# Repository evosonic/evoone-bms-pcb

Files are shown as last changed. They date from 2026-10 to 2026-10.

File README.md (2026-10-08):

# EvoOne BMS PCB (EVO2513 v0.5.0)

KiCad project for the EvoOne battery management board, EVO2513 revision 0.5.0.

The design was converted to KiCad from the Altium sources supplied by Lattech.
The raw import needed several fixes before the schematic and PCB agreed; see
[Fixes after import](#fixes-after-import).

## Board

| | |
|---|---|
| Outline | 110 × 69 mm |
| Layers | 8 copper (F.Cu, In1–In6.Cu, B.Cu) |
| Thickness | 1.584 mm |
| Components | ~230 footprints |
| Tool | KiCad 10.0 |

## Schematic sheets

The schematic is hierarchical: the root sheet `EVO2513-0_5_0.kicad_sch` holds
one sheet symbol per sheet, and each sheet is its own file. Open it from
`EVO2513-0_5_0.kicad_pro`.

| Sheet | Function | Key parts |
|---|---|---|
| S01 External Connectors | Board connectors, mounting and pogo test pads | J1–J6, BON1–26 |
| S02 Input Protection | Over/under-voltage and reverse-voltage protection on the input | LTC4365, DMT4011LFG N-FETs |
| S03 BMS Input and Output Monitor | Input/output current sensing and power-path switching | LTC1960, DMP3018SFV P-FETs, 2512 shunts |
| S04 Charger Regulation | Charger switching stage | LTC1960, L1 4.7 µH |
| S05 Battery Management | Dual-battery selection and management | LTC1960 |
| S06 STEP-Up Step-Down Reg | Buck-boost output regulator | LM51772, L2 0.68 µH |
| S07 Load Switch and I-Sense | Output load switches and current-sense amplifiers | TPS22811 ×3, TLV9002 ×2 |
| S08 IO Expander | SPI I/O expander driving the rail enables and reading the faults | PCAL9714 |

The LTC1960 dual battery charger/selector is a single IC (U1) split across
sheets S03–S05.

Nets that cross sheets leave each sheet through a hierarchical label and a
pin on its sheet symbol, and the root sheet joins the pins with local
labels. There are no global labels; those nets are named from the root
(`/DCBMS`, `/POS1`, …). Labels between device sheets show the direction of
power or signal flow (e.g. DCFILTERED is an output of S02 and an input to
S03); links to the connector sheet, S01, stay passive. Labels used on only one sheet are local, and power
nets use power symbols.

## Connectors

| Ref | Part |
|---|---|
| J1 | Molex 1053101204, 2.5 mm pitch |
| J2 | Molex 1053101114, 14-way 2.5 mm pitch, vertical |
| J3 | Amphenol BergStak 10144517-043802LF, 40-pin 0.8 mm receptacle |
| J4 | Molex 1053102204, 2.5 mm pitch |
| J5, J6 | Molex 1053091102, 2-way 2.5 mm pitch |

## Files

- `EVO2513-0_5_0.kicad_pro` — project
- `EVO2513-0_5_0.kicad_sch` — root schematic sheet; `S0x *.kicad_sch` — the
  eight sheets
- `EVO2513-0_5_0.kicad_pcb` — PCB layout
- `EVO2513-0_5_0-import-fps.pretty/` — project footprint library (footprints
  extracted by the Altium import), registered in `fp-lib-table`. Chip resistors
  and capacitors instead use KiCad's standard `Resistor_SMD` and
  `Capacitor_SMD` libraries
- `EVO2513-0_5_0-lattech.kicad_sym` — project symbol library (nickname
  `Lattech Systems`): the Lattech symbols used by the board, extracted from
  the schematics, plus symbols added for the W16 changes (resistor values, PCAL9714). It is not the complete Lattech library, which was not supplied.
- `EVO2513-0_5_0-altium-import.kicad_sym` — the 4 power symbols created by the
  Altium import. Both symbol libraries are registered in `sym-lib-table`.
- `744393580068.stp` — STEP model for part 744393580068 (not currently
  referenced by any footprint in the PCB)

## Design changes (W16 review)

Part and value changes from the W16 schematic review. None changes a
connection or the board copper.

| Ref | Was | Now | Why |
|---|---|---|---|
| Q1, Q3 | DMT4011LFG 40 V | DMT6007LFGQ-7 60 V | Margin against D1's clamp voltage |
| D1 | 1.5SMB27CA | SMBJ26CA (Littelfuse) | Stand-off above the 24 V supply; 42.1 V clamp |
| L1 | 4.7 µH SRP1265A-4R7M | 10 µH SRP1265A-100M | LTC1960's 10 µH minimum |
| C10 | 100 nF 16 V | 100 nF 50 V CC0402KPX7R9BB104 | Sits on VPLUS at ~23 V |
| R54 | 1 kΩ | 768 Ω RC0402FR-07768RL | SBC load-switch current limit (R22, R53, R71 stay 1 kΩ) |
| C16 | 220 nF 50 V C0G 0805 | 220 nF 50 V X7R CC0805KFX7R9BB224 | No 220 nF C0G 0805 exists |
| C39 | 470 pF | 1 nF | SW2 snubber, boost-mode ringing |
| C3, C11, C12, C55 | 35 V | 50 V | DCFILTERED / DCBMS / DCSENSED at 26.3 V |
| C44, C45, C48–C50, C54 | 16 V | 50 V | +12 V and the switched outputs |
| R1 | 620K (description 619K) | 619K | Value and description now agree |
| D4 | Pins named as a series pair | Pins named for the fitted common-anode BAT54A | Drawing and wiring were already right |

Connection options on U5 (LM51772), as 0R 0402 links so either build can be
fitted (lower right of S06):

| Pin | Fitted | DNP (alternative) |
|---|---|---|
| MODE (7) | R86 to GND: power-save mode (W16 review) | R87 back to VCC2/ILIMCOMP: forced PWM, as built before |
| BIAS (40) | R88 to DCBMS, as built before | R89 to +12V, still under review |

U5 can also be configured over I2C instead of by its CFG resistors (right of
the MODE/BIAS links on S06, all DNP as built):

| Ref | Part | Function in the I2C build |
|---|---|---|
| R103 | 0R, CFG1 (ADDR/SLOPE, pin 9) to GND | Enables I2C at address 0x6A. R38 can stay; R103 shorts it |
| R104 | 0R, SDA/CFG3 (pin 5) to J3.34 `MCU_ENDAQ` | SDA to the MCU |
| R105 | 0R, SCL/CFG4 (pin 6) to J3.36 `MCU_ENEXT` | SCL to the MCU |
| R106, R107 | 2.2K to +3V3MCU | SDA and SCL pull-ups (pins rated to 5.8 V) |
| R30, R29 | 5.1K and 1.87K to GND | **Remove**: they are CFG3/CFG4 and would load the bus |

To build for I2C, fit R103–R107 and remove R29 and R30. J3.34 and J3.36 are
also the direct-enable fallback through R97 and R98 (S08): fit R97/R98 or the
I2C option, never both. The MCU pins on J3.34/J3.36 must support I2C.

In the I2C build U5 starts from its register defaults, not the resistor
settings, so firmware must write them before raising REGEN. They are latched
for as long as DCBMS is up, since nRST is tied to DCBMS. Defaults that differ
from the resistor build:
- slope compensation is 0.875 (R38 selects 1.0)
- VCC1, DRSS, hiccup mode and the current-limit options come from registers
  instead of R30 and R29
- the internal DAC becomes the current-limit reference (`ILIM_THRESHOLD`);
  ILIMCOMP is tied to VCC2, so confirm the average current limit stays
  disabled

Overvoltage lockout on the load switches U6, U7 and U9 (TPS22811, S07): a 1 MΩ
1% resistor (R90, R91, R92) from +12V to nEN/OVLO (pin 2), with the
existing 100K 1% pull-downs R51, R52 and R70. Each switch turns off above
13.2 V (12.60–13.81 V over the ±2% pin threshold, 1% resistors and ±0.1 µA pin
leakage) and turns back on below 12.0 V (11.50–12.60 V). To revert, leave
R90–R92 unfitted.
Undervoltage lockout (11.4 V) is deferred: EN/UVLO (pin 1) is also the MCU
enable, and a tight threshold there needs a FET.

Rail enables and faults through a PCAL9714 SPI I/O expander (U11, new sheet
S08). It shares CLOCK/MOSI/MISO with U1 (LTC1960) and has its own chip
select, nCSIO, on J3.32, the pin that was ENSBC. Address 40h (ADDR to GND);
INT has a pull-up but isn't routed off the board. Both supplies are
+3V3MCU. RESET is held low by R100 (100K) and pulled to +3V3MCU by Q23
(BSS138, the same FET as Q20-Q22) whenever +12V is up: R99 100K /
R101 1M put about 11 V on its gate. With the 12 V rail off the expander is
in reset with every port an input, and RESET can never rise above
+3V3MCU, so nothing back-powers the expander. The switch point depends on
Q23's gate threshold (roughly 3.5-4 V on +12V with a BSS138) and has no hysteresis, so
firmware should wait for +12V before configuring the expander.

Q20–Q23 are onsemi BSS138 (SOT-23) in place of the DMN65D8LFB-7
(DFN1006, 1.0 × 0.6 mm). Use the plain BSS138 or another part without a
gate protection zener: the gates sit on 100K pull-ups (R63, R65, R78) and
the R99/R101 divider, and ESD-protected parts such as the 2N7002K or
BSS138BK leak up to about 10 µA, which would pull the PG high level down
by about 1 V. BSS138: IGSS 100 nA, IDSS 0.5 µA, VGS(th) 0.8–1.5 V.

| Port | Net | Function |
|---|---|---|
| P0_0–P0_2 (out) | ENDAQ, ENSBC, ENEXT | U6, U7, U9 enables |
| P0_4–P0_6 (in) | PGDAQ, PGSBC, PGEXT | U6, U7, U9 power good (also still drive the LEDs) |
| P0_7 (in) | nFLT | U5 nFLT/nINT, which was unconnected |
| P0_3, P1_0–P1_5 | — | spare, not connected |

REGEN (U5 enable, J3.12) stays separate: it is still driven straight from
J3 and doesn't pass through the expander.

J3 pins 34 and 36 are now `MCU_ENDAQ` and `MCU_ENEXT`. Each reaches its
enable only through a DNP 0R link (R97, R98), and J3.32
`nCSIO` has R95 (fitted) to the expander CS and R96 (DNP) to ENSBC. To go
back to driving an enable straight from J3, fit its link and leave that
expander port an input. The expander powers up with every port an input
and pulls off, so the existing pull-downs keep the rails off until
firmware sets P0_0–P0_2 as outputs. The MCU firmware must change for this:
the three load-switch enables move from GPIO to SPI, and nCSIO must idle high (R93
pulls it up).

These parts aren't on the board yet: run Update PCB from Schematic, then
place and route R86–R101, Q23, U11, C58 and C59, and re-place Q20–Q22
(now SOT-23). The ENDAQ, ENSBC and ENEXT
tracks from J3 need cutting at the new links.

Still to confirm against what was fitted: C2 (100 µF on the schematic,
82 µF `35SVPF82M` ordered) and C47 (4.7 nF on the schematic, 1.8 nF ordered).

## BOM consolidation

Parts with the same value in different packages or ratings now share one BOM
line. Each change keeps or raises the voltage rating and tolerance.
All resistors are 1%: the OVLO dividers moved from 1M/102K 0.1% to
1M/100K 1%, which keeps the lowest trip point at 12.60 V.

| Refs | Was | Now |
|---|---|---|
| C8, C9, C55 | 1 µF 50 V X5R 0402 | 1 µF 50 V X5R **0603**, as C23, C44, C45, C48–C50, C54 |
| C7, C52, C53, C58, C59 | 100 nF 16 V X7R 0402 | 100 nF **50 V** X7R 0402 `CC0402KPX7R9BB104`, as C10 |
| C37, C38 | 100 nF 16 V X7R 0603 | the same, **0402** (U5 bootstrap caps, ~5 V) |
| C17, C18, C20, C21, C34 | 100 nF 50 V X7R 0402, no part number | `CC0402KPX7R9BB104` |
| C11–C14, C24–C26 | 10 µF 25 V/50 V 1206 | 10 µF 50 V X7R **1210** Murata `GRM32ER71H106KA12L`, as C27 (1210 is easier to source) |
| C27 | 10 µF 50 V X5R 1210 | the same part, X7R |
| C16 | 220 nF 50 V X7R 0805 | the same, **0603** Yageo `CC0603KRX7R9BB224`, as C22 (charger bootstrap cap) |
| C22 | 220 nF 50 V 0603, material field X5R | X7R, as its description already said |
| R43, R44 | 10R 1% 0603 | 10R 1% **0402**, as R4, R5, R24–R27 (U5 current-sense filter, no power) |

Three U5 (LM51772) fixes found during the review:

| Ref | Was | Now | Why |
|---|---|---|---|
| C30 → **R102** | 22 µF 6.3 V 0603 on VCC1 | 10K 1% 0402 to GND, as R7 | VCC1 is disabled (R30 5.1K on CFG3); the datasheet says tie a disabled VCC1 to GND through a resistor, not leave it floating |
| C32 | 22 µF 6.3 V X5R 0603 on VCC2 | 22 µF **16 V** X5R **0805** Murata `GRM21BR61C226ME44L` | VCC2 needs 6 µF minimum; the 0603 keeps only about 5–7 µF at 5 V |
| R29 | 1.9K | **1.87K** | CFG4 setting #3 accepts 1.814–1.926 kΩ (1.87K typical); 1.9K isn't a 1% value, and 1.91K can reach 1.929 kΩ |

New library symbols: `Capacitor 10uF 50V X7R 1210`, `Capacitor 22uF 16V X5R
0805` and `Resistor 1.87K 1% 0402`.
Run Update PCB from Schematic to swap the footprints. Parts that grow overlap
their neighbours' courtyards and need moving: the 0603s for C8, C9 and C55 by
up to 0.9 mm (C55 against C5 and C7, C8 against R8, C9 against R15 and C10),
the 1210s by about 0.15 mm (C11/C12/C27, C24/C26, C25 against C23), and C32
by 0.3 mm against C38 (before C38 shrinks to 0402) and 0.1 mm against TH2.

## Fixes after import

Each fix is a separate commit on top of the initial import.

| Problem in the raw import | Fix |
|---|---|
| Every symbol's Value field was `${ALTIUM_VALUE}`, resolved through a per-symbol field | Copied the real value into Value (209 symbols); the 26 BON pogo pads, which had no value, are `POGO-1` |
| 12 Footprint fields differed from the placed footprint only in letter case, so library lookup failed | Fields now name the exact footprint used on the PCB (J2, J5, J6, M2–M6, FL1, D9, D10, L2) |
| An imported `FOOTPRINT` field holding the bare package name (`0402`, `SMA`, …) overrode the real Footprint field, since KiCad matches field names case-insensitively | Renamed to `ALTIUM_FOOTPRINT` on all 237 symbols |
| Altium net labels became KiCad local labels, which don't connect across sheets, splitting 35 nets | Converted the 78 labels for those nets to global labels |
| 44 embedded library symbols drew Altium special strings `=Value` and `=FootPrint` as literal text | `=Value` replaced with `${VALUE}`; `=FootPrint` replaced by showing each part's own `ALTIUM_FOOTPRINT` field in the same place, so parts show their part number and package as in Altium |
| All 99 power symbols were unannotated (`#PWR?`) | Annotated `#PWR1`–`#PWR99` |
| The "Lattech Systems" symbol library wasn't available, so symbols existed only as copies embedded in the schematics, some in several slightly different versions | Exported the symbols to project libraries under their original library names, and made every schematic use one definition per symbol |
| Chip resistor and capacitor footprints had poor pads (0402s used 0.635 mm circular pads) and caused tombstoning | Replaced all 139 with KiCad standard IPC-7351 nominal footprints (`Resistor_SMD`, `Capacitor_SMD`) in place: same position, rotation and nets, zones refilled |
| PCB footprints were linked to the imported symbols by mismatched internal IDs, and nets used Altium names | Ran Update PCB from Schematic: no errors, placement and copper unchanged, all 147 nets match the schematic |
| KiCad design rules were defaults (0.2 mm clearance and track, 0.3 mm min hole), not the Altium rules | Set to the rules in the Altium `.PcbDoc`: 0.15 mm clearance, track and annular ring, 0.15 mm min hole, 0.3 mm hole-to-hole, and `EVO2513-0_5_0.kicad_dru` for the 0.3 mm BON pad-to-pad rule |
| FL1's ground land had no pad number, so its 38 GND vias showed as shorts | Numbered pad 4 (GND) on the board and in the project footprint library |
| The two mounting holes had no reference designator | Named H1 and H2, board-only, excluded from BOM and position files |
| 14 zero-length track segments | Removed |
| FL1's courtyard had a centre cross drawn on F.CrtYd, so KiCad saw an open (malformed) courtyard | Moved the cross to F.Fab on the board and in the project footprint library |
| Two vias sat in 0402 pads (R13 pad 2, R54 pad 2), connected on F.Cu only, and could wick solder | Removed |
| 9 tracks ran within 0.15 mm of the new R/C pad corners, B.Cu tracks passed 0.10 mm from J2 pins 9/10, and the ENEXT track 0.21 mm from J3's peg hole | Rerouted; 15 small R/C parts and 3 GND vias moved 0.1 mm |
| Net class patterns named Altium's auto-generated nets, so 13 power nets were in the Default class | Patterns point at the current net names |
| Every sheet sat 43 mil off the 50 mil connection grid in Y | Shifted each sheet's contents 7 mil onto the grid, and moved the few remaining off-grid wire corners on S06 onto it |
| 9 wires ran past their labels, leaving dangling ends | Trimmed back to the label |
| GND, +12V, +3V3MCU and +5V had no power source for ERC | Added PWR_FLAG symbols |
| Title blocks used the Altium formula `${COPY(DOCUMENTNAME,…)}` for the sheet title | Replaced with each sheet's title |
| The import made seven KiCad 10 top-level sheets, so `kicad-cli` only loaded S01, and every title block read "sheet 7 of 7" | Added a root sheet with the seven as sub-sheets (S01's content moved to `S01 External Connectors.kicad_sch`); sheet numbers now come from the page number |

Symbols still carry their imported Altium fields (`ALTIUM_VALUE`,
`ALTIUM_FOOTPRINT`, `MANUFACTURER`, `MANUFACTURER_PN`, …) for reference.

### Known remaining issues

- The KiCad default title block is drawn over the imported Altium one.
- The mounting spacers use two near-identical footprints: M1 uses
  `Mech Spacer Wurth 78614150960 Through M3`, and M2–M6 use the upper-case
  variant.
- DRC still reports: 80 hole-clearance hits, each Molex connector's own NPTH
  locating peg 0.18 mm from its pin pads (J1, J2, J4–J6; Altium had no
  hole-clearance rule); 199 silkscreen texts at 0.6 mm,
  below KiCad's 0.8 mm minimum; 16 board-edge clearance hits from the
  layer-order markers, which cross the edge on purpose; and 11 courtyard
  overlaps where parts sit closer than IPC courtyards allow, e.g. TH1/TH2.
- The design relies on via-in-pad: over 700 vias sit in pads (FET tabs, QFN
  exposed pads, FL1, the 2512 shunts, and 0402/0603 capacitors). Order the
  board with vias filled and capped; open vias would wick solder from the
  small pads.

Generated outputs (netlists, backups, per-user `.kicad_prl` settings) are not
tracked; see `.gitignore`.

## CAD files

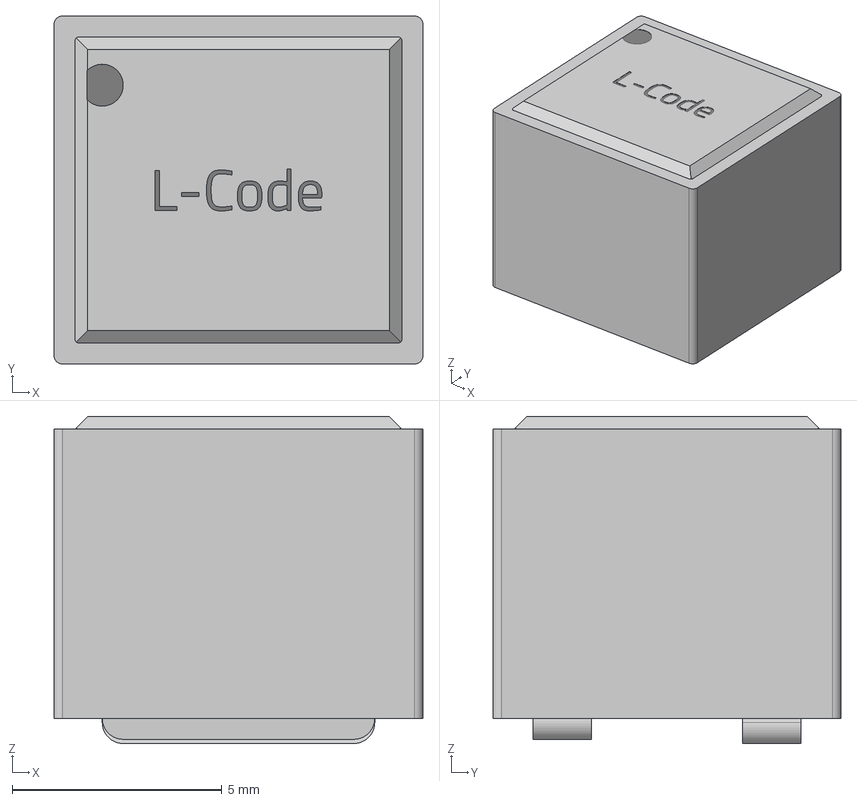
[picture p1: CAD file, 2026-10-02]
744393580068.stp
8.80 x 8.30 x 7.80 mm

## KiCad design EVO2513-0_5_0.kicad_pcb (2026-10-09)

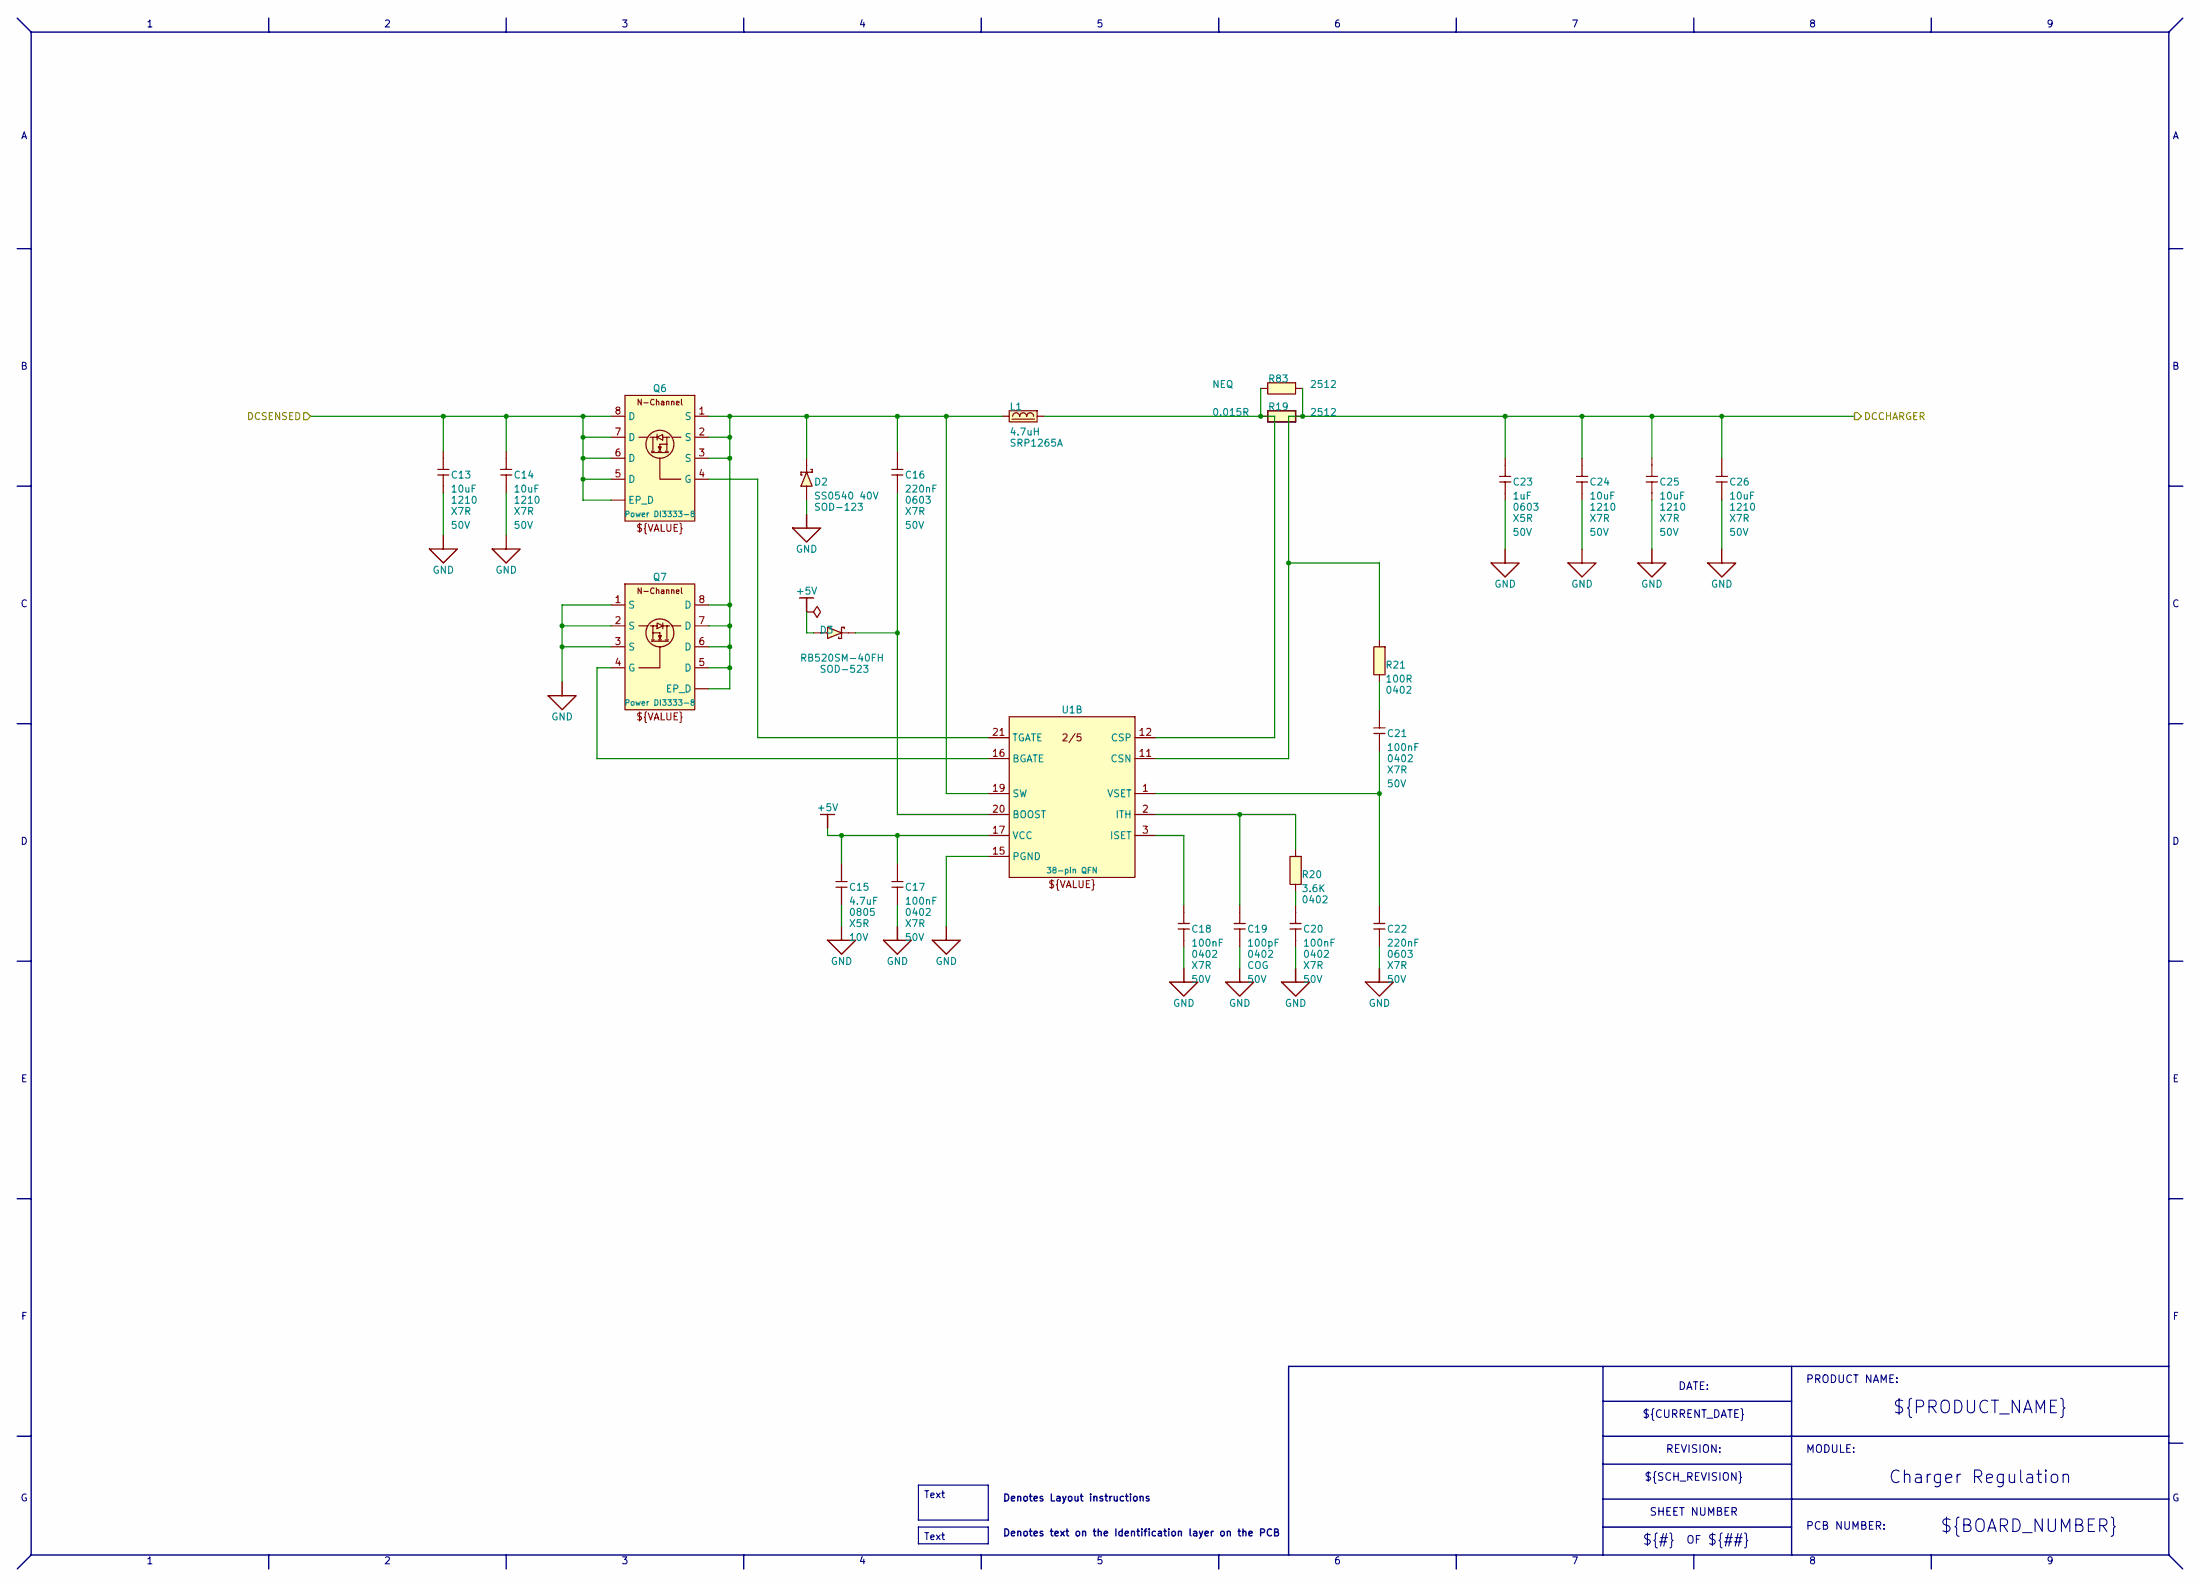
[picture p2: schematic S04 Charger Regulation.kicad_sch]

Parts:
C13, C14, C24, C25, C26: 10uF; C_1210_3225Metric; VOLTAGE 50V; MANUFACTURER_PN GRM32ER71H106KA12L
C15: 4.7uF; C_0805_2012Metric; VOLTAGE 10V
C16, C22: 220nF; C_0603_1608Metric; VOLTAGE 50V; MANUFACTURER_PN CC0603KRX7R9BB224
C17, C18, C20, C21: 100nF; C_0402_1005Metric; VOLTAGE 50V; MANUFACTURER_PN CC0402KPX7R9BB104
C19: 100pF; C_0402_1005Metric; VOLTAGE 50V; MANUFACTURER_PN ?
C23: 1uF; C_0603_1608Metric; VOLTAGE 50V; MANUFACTURER_PN ?
D2: SS0540 40V; Diode SOD123; MANUFACTURER_PN SS0540
D3: RB520SM-40FH; Diode SOD523; MANUFACTURER_PN RB520SM-40FH
L1: 10uH; IND Bourns SRRP1265A; MANUFACTURER_PN SRP1265A-100M
Q6, Q7: DMT4011LFG; Power DI3333-8 B3.3 x 3.3 P0.65 Tab 8-Pin; MANUFACTURER_PN DMT4011LFG
R19: 0.015R; R_2512_6332Metric; MANUFACTURER_PN CRA2512-FZ-R015ELF
R20: 3.6K; R_0402_1005Metric
R21: 100R; R_0402_1005Metric; MANUFACTURER_PN ?
R83: NEQ; R_2512_6332Metric; MANUFACTURER_PN Res 2512
U1: LTC1960; QFN B5x7 P0-5 38-Pin EP; MANUFACTURER_PN LTC1960CUHF

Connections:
+5V: C15.2, C17.2, D3.2 (A), U1.17 (VCC); also elsewhere on the board
/DCCHARGER: C23.2, C24.2, C25.2, C26.2, R19.2, R21.2, R83.2, U1.11 (CSN); also elsewhere on the board
/DCSENSED: C13.2, C14.2, Q6.5 (D), Q6.6 (D), Q6.7 (D), Q6.8 (D), Q6.9 (EP_D); also elsewhere on the board
GND: C13.1, C14.1, C15.1, C17.1, C18.1, C19.1, C20.1, C22.1, C23.1, C24.1, C25.1, C26.1, D2.2 (A), Q7.1 (S), Q7.2 (S), Q7.3 (S), U1.15 (PGND); also elsewhere on the board
unnamed: C20.2, R20.1
unnamed: C21.2, R21.1
unnamed: C16.2, D2.1 (C), L1.1, Q6.1 (S), Q6.2 (S), Q6.3 (S), Q7.5 (D), Q7.6 (D), Q7.7 (D), Q7.8 (D), Q7.9 (EP_D), U1.19 (SW)
unnamed: C16.1, D3.1 (C), U1.20 (BOOST)
unnamed: Q6.4 (G), U1.21 (TGATE)
unnamed: Q7.4 (G), U1.16 (BGATE)
unnamed: L1.2, R19.1, R83.1, U1.12 (CSP)
unnamed: C18.2, U1.3 (ISET)
unnamed: C19.2, R20.2, U1.2 (ITH)
unnamed: C21.1, C22.2, U1.1 (VSET)

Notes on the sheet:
${##}
Charger Regulation
REVISION:
${BOARD_NUMBER}
${#}
${PRODUCT_NAME}
Denotes Layout instructions
PCB NUMBER:
${CURRENT_DATE}
PRODUCT NAME:
${SCH_REVISION}
Denotes text on the Identification layer on the PCB
MODULE:
SHEET NUMBER
DATE:
Text

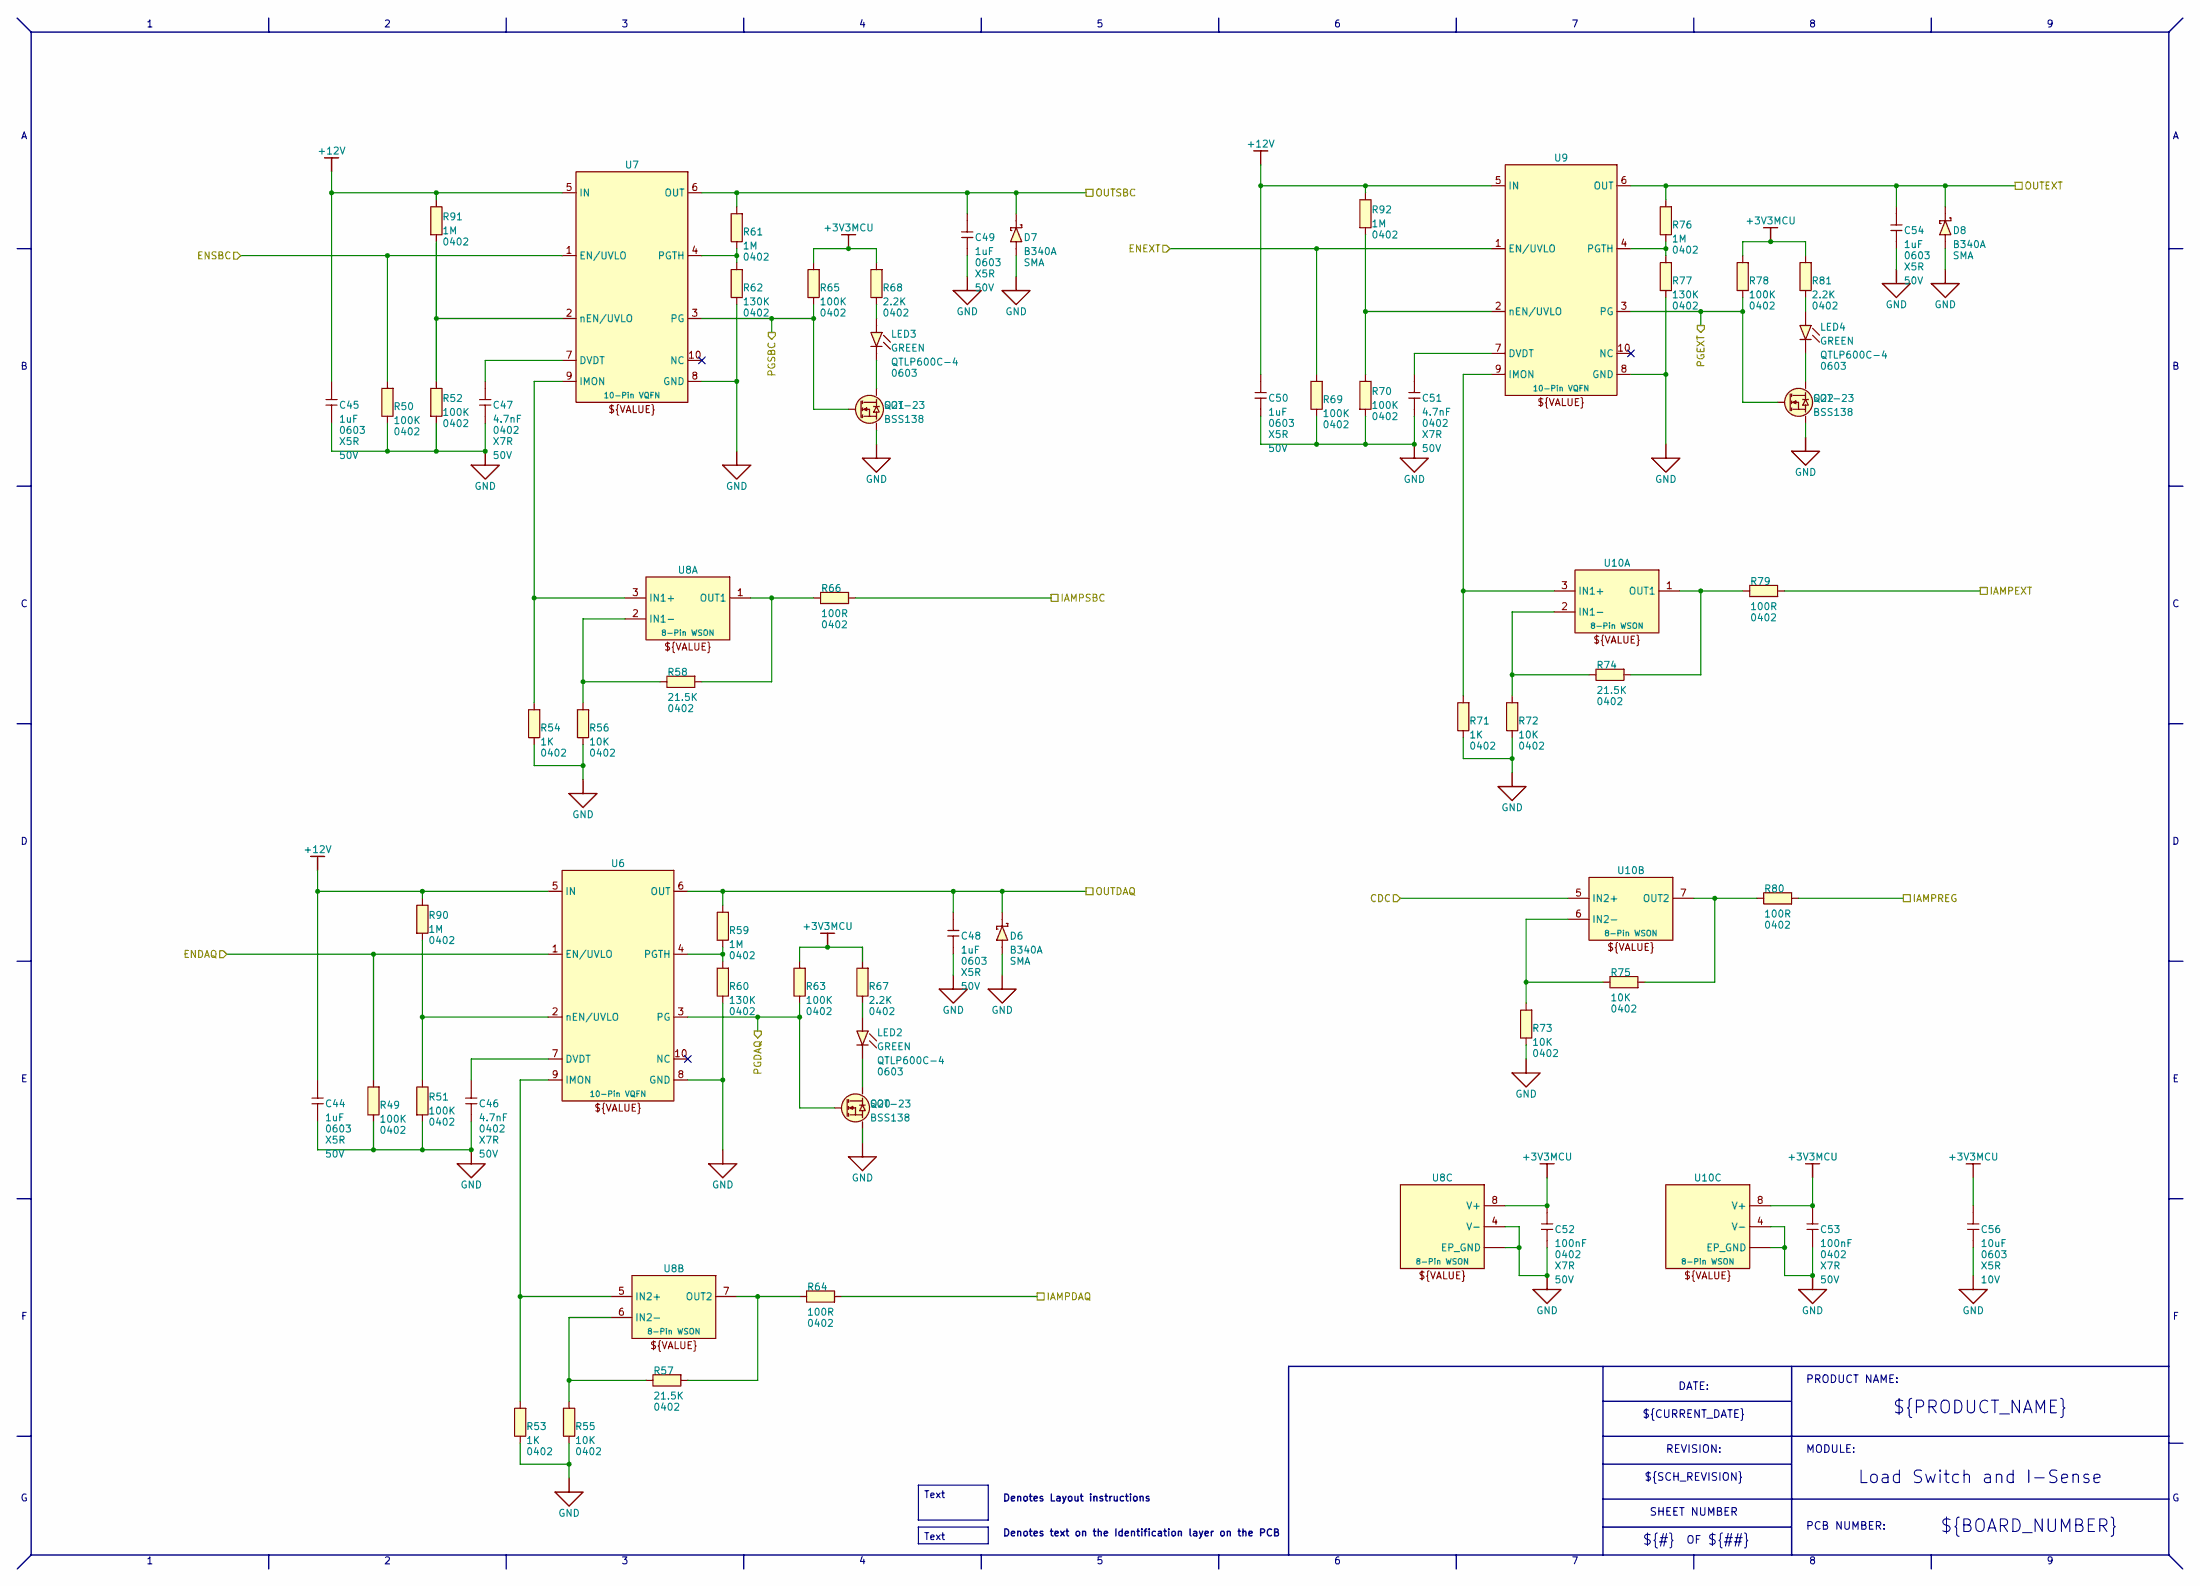
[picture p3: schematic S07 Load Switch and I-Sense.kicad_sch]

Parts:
C44, C45, C48, C49, C50, C54: 1uF; C_0603_1608Metric; VOLTAGE 50V; MANUFACTURER_PN ?
C46, C47, C51: 4.7nF; C_0402_1005Metric; VOLTAGE 50V
C52, C53: 100nF; C_0402_1005Metric; VOLTAGE 50V; MANUFACTURER_PN CC0402KPX7R9BB104
C56: 10uF; C_0603_1608Metric; VOLTAGE 10V; MANUFACTURER_PN ??
D6, D7, D8: B340A; Diode DO-214AC SMA; MANUFACTURER_PN B340A
LED2, LED3, LED4: QTLP600C-4; LED 0603 H0-7 (C); MANUFACTURER_PN QTLP600C-4
Q20, Q21, Q22: BSS138; SOT-23; MANUFACTURER_PN BSS138
R49, R50, R51, R52, R63, R65, R69, R70, R78: 100K; R_0402_1005Metric; MANUFACTURER_PN ?
R53, R71: 1K; R_0402_1005Metric; MANUFACTURER_PN ?
R54: 768R; R_0402_1005Metric; MANUFACTURER_PN RC0402FR-07768RL
R55, R56, R72, R73, R75: 10K; R_0402_1005Metric; MANUFACTURER_PN ?
R57, R58, R74: 21.5K; R_0402_1005Metric; MANUFACTURER_PN ?
R59, R61, R76, R90, R91, R92: 1M; R_0402_1005Metric; MANUFACTURER_PN ?
R60, R62, R77: 130K; R_0402_1005Metric
R64, R66, R79, R80: 100R; R_0402_1005Metric; MANUFACTURER_PN ?
R67, R68, R81: 2.2K; R_0402_1005Metric; MANUFACTURER_PN ?
U6, U7, U9: TPS22811; VQFN-HR B2.0x2.0x1.0 10-Pin TI LM73100RPW; MANUFACTURER_PN TPS22811LRPWR
U8, U10: TLV9002IDSG; WSON B2x2 P0-5 8-Pin EP; MANUFACTURER_PN TLV9002IDSG

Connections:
+3V3MCU: C52.2, C53.2, C56.2, R63.2, R65.2, R67.2, R68.2, R78.2, R81.2, U8.8 (V+), U10.8 (V+); also elsewhere on the board
+12V: C44.2, C45.2, C50.2, R90.1, R91.1, R92.1, U6.5 (IN), U7.5 (IN), U9.5 (IN); also elsewhere on the board
/CDC: U10.5 (IN2+); also elsewhere on the board
/ENDAQ: R49.2, U6.1 (EN/UVLO); also elsewhere on the board
/ENEXT: R69.2, U9.1 (EN/UVLO); also elsewhere on the board
/ENSBC: R50.2, U7.1 (EN/UVLO); also elsewhere on the board
/IAMPDAQ: R64.2; also elsewhere on the board
/IAMPEXT: R79.2; also elsewhere on the board
/IAMPREG: R80.2; also elsewhere on the board
/IAMPSBC: R66.2; also elsewhere on the board
/OUTDAQ: C48.2, D6.1 (C), R59.2, U6.6 (OUT); also elsewhere on the board
/OUTEXT: C54.2, D8.1 (C), R76.2, U9.6 (OUT); also elsewhere on the board
/OUTSBC: C49.2, D7.1 (C), R61.2, U7.6 (OUT); also elsewhere on the board
/PGDAQ: Q20.1 (G), R63.1, U6.3 (PG); also elsewhere on the board
/PGEXT: Q22.1 (G), R78.1, U9.3 (PG); also elsewhere on the board
/PGSBC: Q21.1 (G), R65.1, U7.3 (PG); also elsewhere on the board
GND: C44.1, C45.1, C46.1, C47.1, C48.1, C49.1, C50.1, C51.1, C52.1, C53.1, C54.1, C56.1, D6.2 (A), D7.2 (A), D8.2 (A), Q20.2 (S), Q21.2 (S), Q22.2 (S), R49.1, R50.1, R51.2, R52.2, R53.1, R54.1, R55.1, R56.1, R60.1, R62.1, R69.1, R70.2, R71.1, R72.1, R73.1, R77.1, U6.8 (GND), U7.8 (GND), U8.4 (V-), U8.9 (EP_GND), U9.8 (GND), U10.4 (V-), U10.9 (EP_GND); also elsewhere on the board
unnamed: LED2.2 (A), R67.1
unnamed: LED2.1 (C), Q20.3 (D)
unnamed: LED3.2 (A), R68.1
unnamed: LED3.1 (C), Q21.3 (D)
unnamed: LED4.2 (A), R81.1
unnamed: LED4.1 (C), Q22.3 (D)
unnamed: C46.2, U6.7 (DVDT)
unnamed: R53.2, U6.9 (IMON), U8.5 (IN2+)
unnamed: R59.1, R60.2, U6.4 (PGTH)
unnamed: R51.1, R90.2, U6.2 (nEN/UVLO)
unnamed: C47.2, U7.7 (DVDT)
unnamed: R54.2, U7.9 (IMON), U8.3 (IN1+)
unnamed: R61.1, R62.2, U7.4 (PGTH)
unnamed: R52.1, R91.2, U7.2 (nEN/UVLO)
unnamed: R56.2, R58.1, U8.2 (IN1-)
unnamed: R58.2, R66.1, U8.1 (OUT1)
unnamed: R55.2, R57.1, U8.6 (IN2-)
unnamed: R57.2, R64.1, U8.7 (OUT2)
unnamed: C51.2, U9.7 (DVDT)
unnamed: R76.1, R77.2, U9.4 (PGTH)
unnamed: R70.1, R92.2, U9.2 (nEN/UVLO)
unnamed: R71.2, U9.9 (IMON), U10.3 (IN1+)
unnamed: R72.2, R74.1, U10.2 (IN1-)
unnamed: R74.2, R79.1, U10.1 (OUT1)
unnamed: R73.2, R75.1, U10.6 (IN2-)
unnamed: R75.2, R80.1, U10.7 (OUT2)

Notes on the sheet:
${PRODUCT_NAME}
Denotes Layout instructions
SHEET NUMBER
MODULE:
${SCH_REVISION}
REVISION:
PRODUCT NAME:
DATE:
PCB NUMBER:
Load Switch and I-Sense
${CURRENT_DATE}
${BOARD_NUMBER}
${##}
Denotes text on the Identification layer on the PCB
${#}
Text

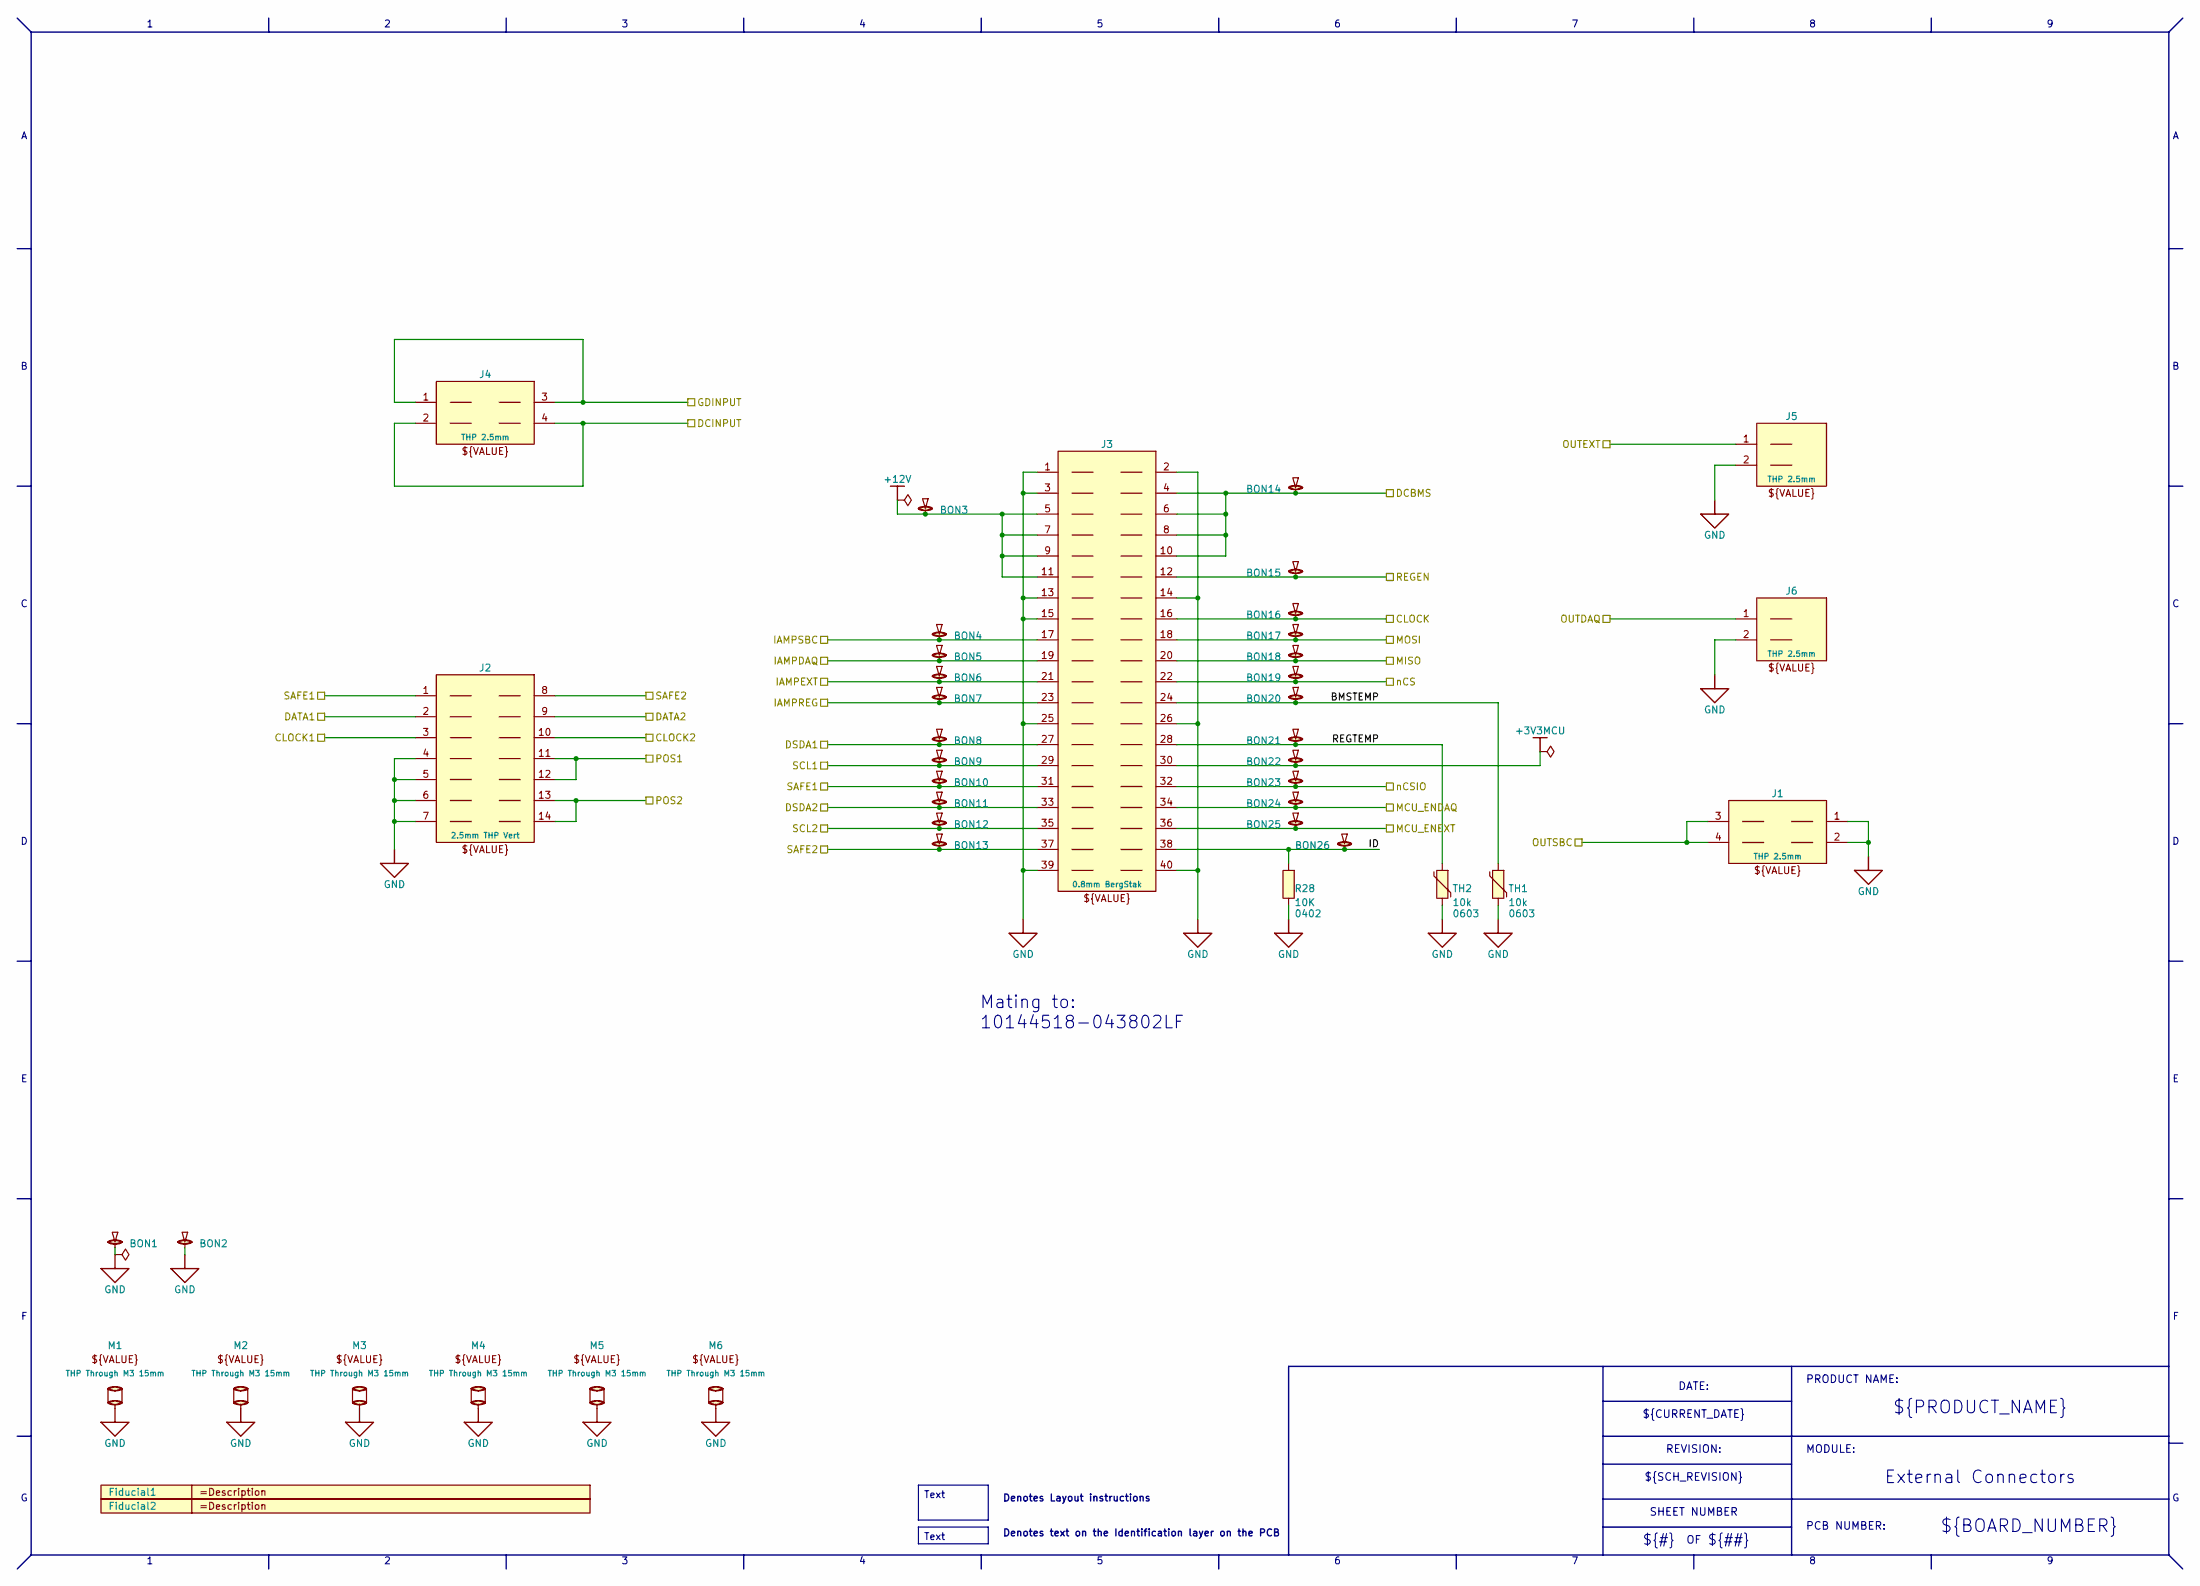
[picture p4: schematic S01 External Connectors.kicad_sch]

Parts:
BON1, BON2, BON3, BON4, BON5, BON6, BON7, BON8, BON9, BON10, BON11, BON12, BON13, BON14, BON15, BON16, BON17, BON18, BON19, BON20, BON21, BON22, BON23, BON24, BON25, BON26: POGO-1; TEST PIN BON 1-25mm SMD Pad (POGO-1)
Fiducial1, Fiducial2: Fiducial; Fiducial-50
J1: 1053101204; Connector Molex 105310xx04 4POS 2.5mm THP; MANUFACTURER_PN 1053101204
J2: 1053101114; CONNECTOR MOLEX 1053101114 2.5MM THP; MANUFACTURER_PN 1053101114
J3: 10144517-043802LF; Connector Amphenol BergStak 10144517-043802LF 40-Pin Recept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; MANUFACTURER_PN 10144517-042802LF
J4: 1053102204; Connector Molex 105310xx04 4POS 2.5mm THP; MANUFACTURER_PN 1053102204
J5, J6: 1053091102; CONNECTOR MOLEX 1053091102 2POS 2.5MM THP; MANUFACTURER_PN 1053091102
M1: 78614150960; Mech Spacer Wurth 78614150960 Through M3
M2, M3, M4, M5, M6: 78614150960; MECH SPACER WURTH 78614150960 THROUGH M3
R28: 10K; R_0402_1005Metric; MANUFACTURER_PN ?
TH1, TH2: 10k; R_0603_1608Metric; MANUFACTURER_PN NCU18XH103E6SRB

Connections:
+3V3MCU: BON22.1 (1_1), J3.30 (I/O); also elsewhere on the board
+12V: BON3.1 (1_1), J3.5 (I/O), J3.7 (I/O), J3.9 (I/O), J3.11 (I/O); also elsewhere on the board
/CLOCK: BON16.1 (1_1), J3.16 (I/O); also elsewhere on the board
/CLOCK1: J2.3 (I/O); also elsewhere on the board
/CLOCK2: J2.10 (I/O); also elsewhere on the board
/DATA1: J2.2 (I/O); also elsewhere on the board
/DATA2: J2.9 (I/O); also elsewhere on the board
/DCBMS: BON14.1 (1_1), J3.4 (I/O), J3.6 (I/O), J3.8 (I/O), J3.10 (I/O); also elsewhere on the board
/DCINPUT: J4.2 (I/O), J4.4 (I/O); also elsewhere on the board
/DSDA1: BON8.1 (1_1), J3.27 (I/O); also elsewhere on the board
/DSDA2: BON11.1 (1_1), J3.33 (I/O); also elsewhere on the board
/GDINPUT: J4.1 (I/O), J4.3 (I/O); also elsewhere on the board
/IAMPDAQ: BON5.1 (1_1), J3.19 (I/O); also elsewhere on the board
/IAMPEXT: BON6.1 (1_1), J3.21 (I/O); also elsewhere on the board
/IAMPREG: BON7.1 (1_1), J3.23 (I/O); also elsewhere on the board
/IAMPSBC: BON4.1 (1_1), J3.17 (I/O); also elsewhere on the board
/MCU_ENDAQ: BON24.1 (1_1), J3.34 (I/O); also elsewhere on the board
/MCU_ENEXT: BON25.1 (1_1), J3.36 (I/O); also elsewhere on the board
/MISO: BON18.1 (1_1), J3.20 (I/O); also elsewhere on the board
/MOSI: BON17.1 (1_1), J3.18 (I/O); also elsewhere on the board
/OUTDAQ: J6.1 (I/O); also elsewhere on the board
/OUTEXT: J5.1 (I/O); also elsewhere on the board
/OUTSBC: J1.3 (I/O), J1.4 (I/O); also elsewhere on the board
/POS1: J2.11 (I/O), J2.12 (I/O); also elsewhere on the board
/POS2: J2.13 (I/O), J2.14 (I/O); also elsewhere on the board
/REGEN: BON15.1 (1_1), J3.12 (I/O); also elsewhere on the board
/S01 External Connectors/BMSTEMP: BON20.1 (1_1), J3.24 (I/O), TH1.2
/S01 External Connectors/ID: BON26.1 (1_1), J3.38 (I/O), R28.2
/S01 External Connectors/REGTEMP: BON21.1 (1_1), J3.28 (I/O), TH2.2
/SAFE1: BON10.1 (1_1), J2.1 (I/O), J3.31 (I/O); also elsewhere on the board
/SAFE2: BON13.1 (1_1), J2.8 (I/O), J3.37 (I/O); also elsewhere on the board
/SCL1: BON9.1 (1_1), J3.29 (I/O); also elsewhere on the board
/SCL2: BON12.1 (1_1), J3.35 (I/O); also elsewhere on the board
/nCS: BON19.1 (1_1), J3.22 (I/O); also elsewhere on the board
/nCSIO: BON23.1 (1_1), J3.32 (I/O); also elsewhere on the board
GND: BON1.1 (1_1), BON2.1 (1_1), J1.1 (I/O), J1.2 (I/O), J2.4 (I/O), J2.5 (I/O), J2.6 (I/O), J2.7 (I/O), J3.1 (I/O), J3.2 (I/O), J3.3 (I/O), J3.13 (I/O), J3.14 (I/O), J3.15 (I/O), J3.25 (I/O), J3.26 (I/O), J3.39 (I/O), J3.40 (I/O), J5.2 (I/O), J6.2 (I/O), M1.1 (1_1), M2.1 (1_1), M3.1 (1_1), M4.1 (1_1), M5.1 (1_1), M6.1 (1_1), R28.1, TH1.1, TH2.1; also elsewhere on the board

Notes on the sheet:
Denotes Layout instructions
PCB NUMBER:
${BOARD_NUMBER}
REVISION:
${#}
PRODUCT NAME:
${PRODUCT_NAME}
SHEET NUMBER
${SCH_REVISION}
MODULE:
DATE:
External Connectors
${CURRENT_DATE}
${##}
Denotes text on the Identification layer on the PCB
Mating to: 10144518-043802LF
Text

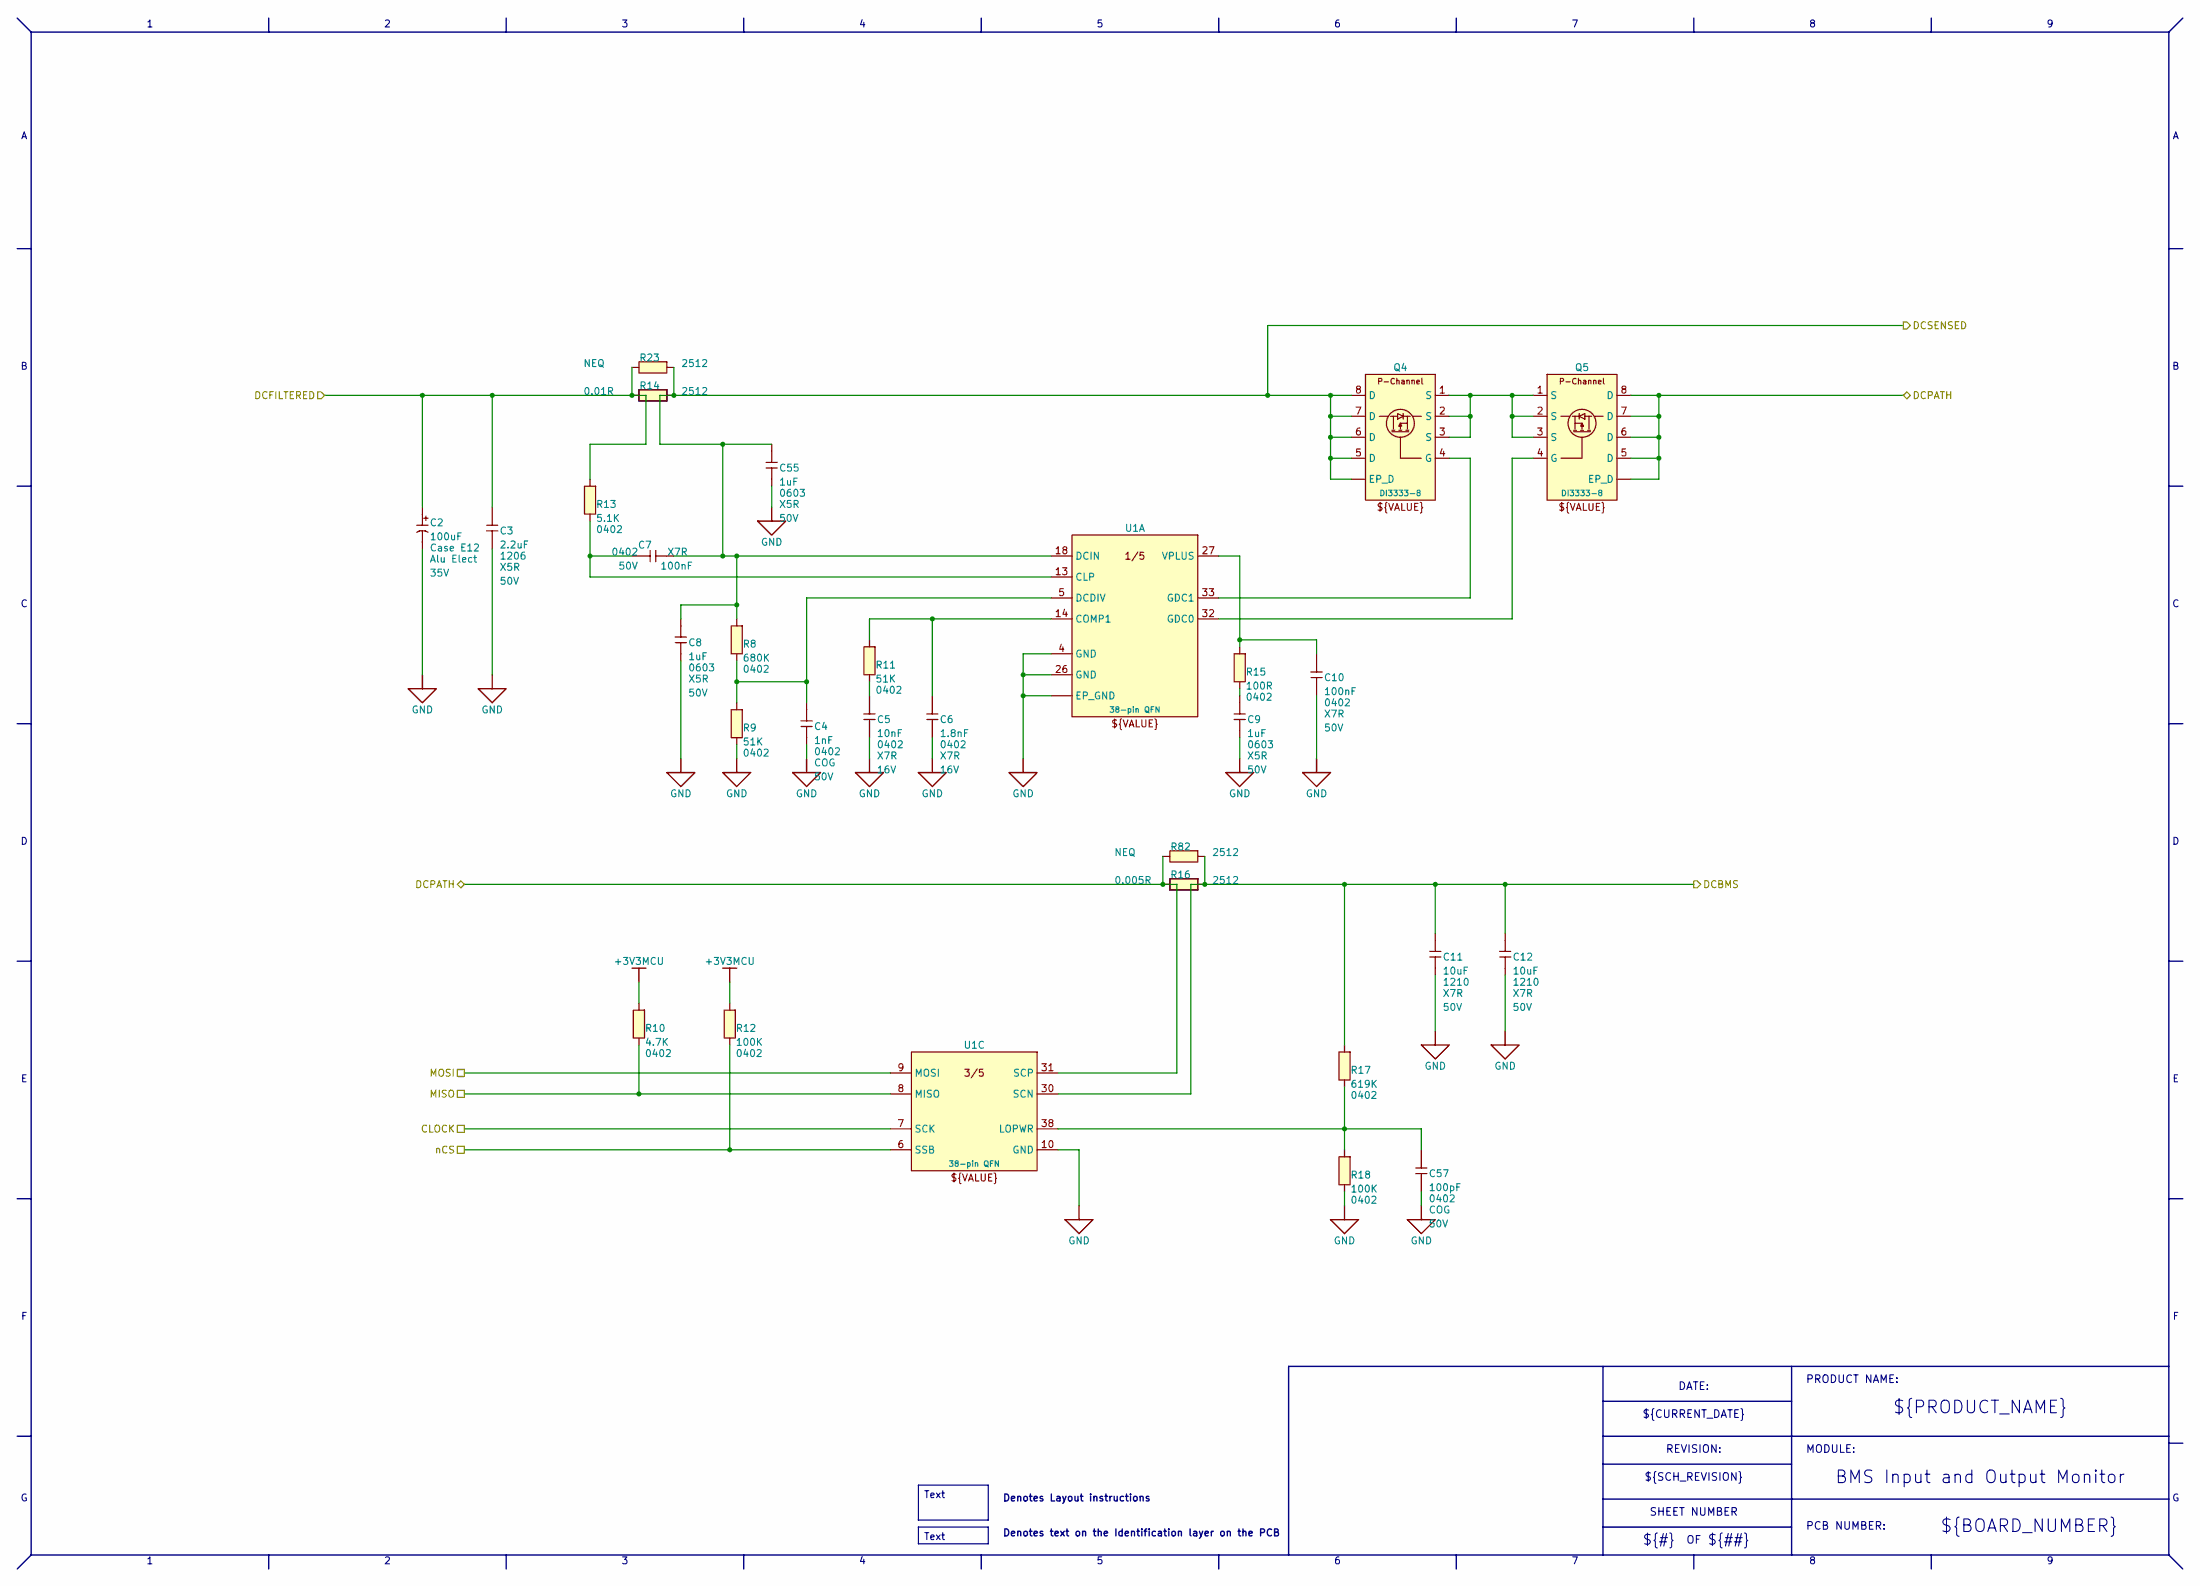
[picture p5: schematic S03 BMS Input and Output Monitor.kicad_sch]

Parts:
C2: 100uF; CAP Panasonic CASE-E12; VOLTAGE 35V; MANUFACTURER_PN 35SVPF82M
C3: 2.2uF; C_1206_3216Metric; VOLTAGE 50V
C4: 1nF; C_0402_1005Metric; VOLTAGE 50V
C5: 10nF; C_0402_1005Metric; VOLTAGE 16V; MANUFACTURER_PN GRM155R71C103K
C6: 1.8nF; C_0402_1005Metric; VOLTAGE 16V
C7, C10: 100nF; C_0402_1005Metric; VOLTAGE 50V; MANUFACTURER_PN CC0402KPX7R9BB104
C8, C9, C55: 1uF; C_0603_1608Metric; VOLTAGE 50V; MANUFACTURER_PN ?
C11, C12: 10uF; C_1210_3225Metric; VOLTAGE 50V; MANUFACTURER_PN GRM32ER71H106KA12L
C57: 100pF; C_0402_1005Metric; VOLTAGE 50V; MANUFACTURER_PN ?
Q4, Q5: DMP3018SFV; Power DI3333-8 B3.3 x 3.3 P0.65 Tab 8-Pin; MANUFACTURER_PN DMP3018SFV
R8: 680K; R_0402_1005Metric
R9, R11: 51K; R_0402_1005Metric
R10: 4.7K; R_0402_1005Metric; MANUFACTURER_PN ?
R12, R18: 100K; R_0402_1005Metric; MANUFACTURER_PN ?
R13: 5.1K; R_0402_1005Metric; MANUFACTURER_PN ?
R14: 0.01R; R_2512_6332Metric
R15: 100R; R_0402_1005Metric; MANUFACTURER_PN ?
R16: 0.005R; R_2512_6332Metric; MANUFACTURER_PN CRE2512-FZ-R005E-3
R17: 619K; R_0402_1005Metric; MANUFACTURER_PN ?
R23, R82: NEQ; R_2512_6332Metric; MANUFACTURER_PN Res 2512
U1: LTC1960; QFN B5x7 P0-5 38-Pin EP; MANUFACTURER_PN LTC1960CUHF

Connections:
+3V3MCU: R10.2, R12.2; also elsewhere on the board
/CLOCK: U1.7 (SCK); also elsewhere on the board
/DCBMS: C11.2, C12.2, R16.2, R17.2, R82.2, U1.30 (SCN); also elsewhere on the board
/DCFILTERED: C2.1 (+), C3.2, R13.2, R14.1, R23.1; also elsewhere on the board
/DCPATH: Q5.5 (D), Q5.6 (D), Q5.7 (D), Q5.8 (D), Q5.9 (EP_D), R16.1, R82.1, U1.31 (SCP); also elsewhere on the board
/DCSENSED: C7.2, C8.2, C55.2, Q4.5 (D), Q4.6 (D), Q4.7 (D), Q4.8 (D), Q4.9 (EP_D), R8.2, R14.2, R23.2, U1.18 (DCIN); also elsewhere on the board
/MISO: R10.1, U1.8 (MISO); also elsewhere on the board
/MOSI: U1.9 (MOSI); also elsewhere on the board
/nCS: R12.1, U1.6 (SSB); also elsewhere on the board
GND: C2.2 (-), C3.1, C4.1, C5.1, C6.1, C8.1, C9.1, C10.1, C11.1, C12.1, C55.1, C57.1, R9.1, R18.1, U1.4 (GND), U1.10 (GND), U1.26 (GND), U1.39 (EP_GND); also elsewhere on the board
unnamed: C5.2, R11.1
unnamed: C9.2, R15.1
unnamed: Q4.4 (G), U1.33 (GDC1)
unnamed: Q4.1 (S), Q4.2 (S), Q4.3 (S), Q5.1 (S), Q5.2 (S), Q5.3 (S)
unnamed: Q5.4 (G), U1.32 (GDC0)
unnamed: C7.1, R13.1, U1.13 (CLP)
unnamed: C6.2, R11.2, U1.14 (COMP1)
unnamed: C4.2, R8.1, R9.2, U1.5 (DCDIV)
unnamed: C10.2, R15.2, U1.27 (VPLUS)
unnamed: C57.2, R17.1, R18.2, U1.38 (LOPWR)

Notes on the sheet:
${#}
PCB NUMBER:
SHEET NUMBER
MODULE:
${BOARD_NUMBER}
DATE:
${PRODUCT_NAME}
${##}
Denotes text on the Identification layer on the PCB
PRODUCT NAME:
REVISION:
BMS Input and Output Monitor
Denotes Layout instructions
${CURRENT_DATE}
${SCH_REVISION}
Text

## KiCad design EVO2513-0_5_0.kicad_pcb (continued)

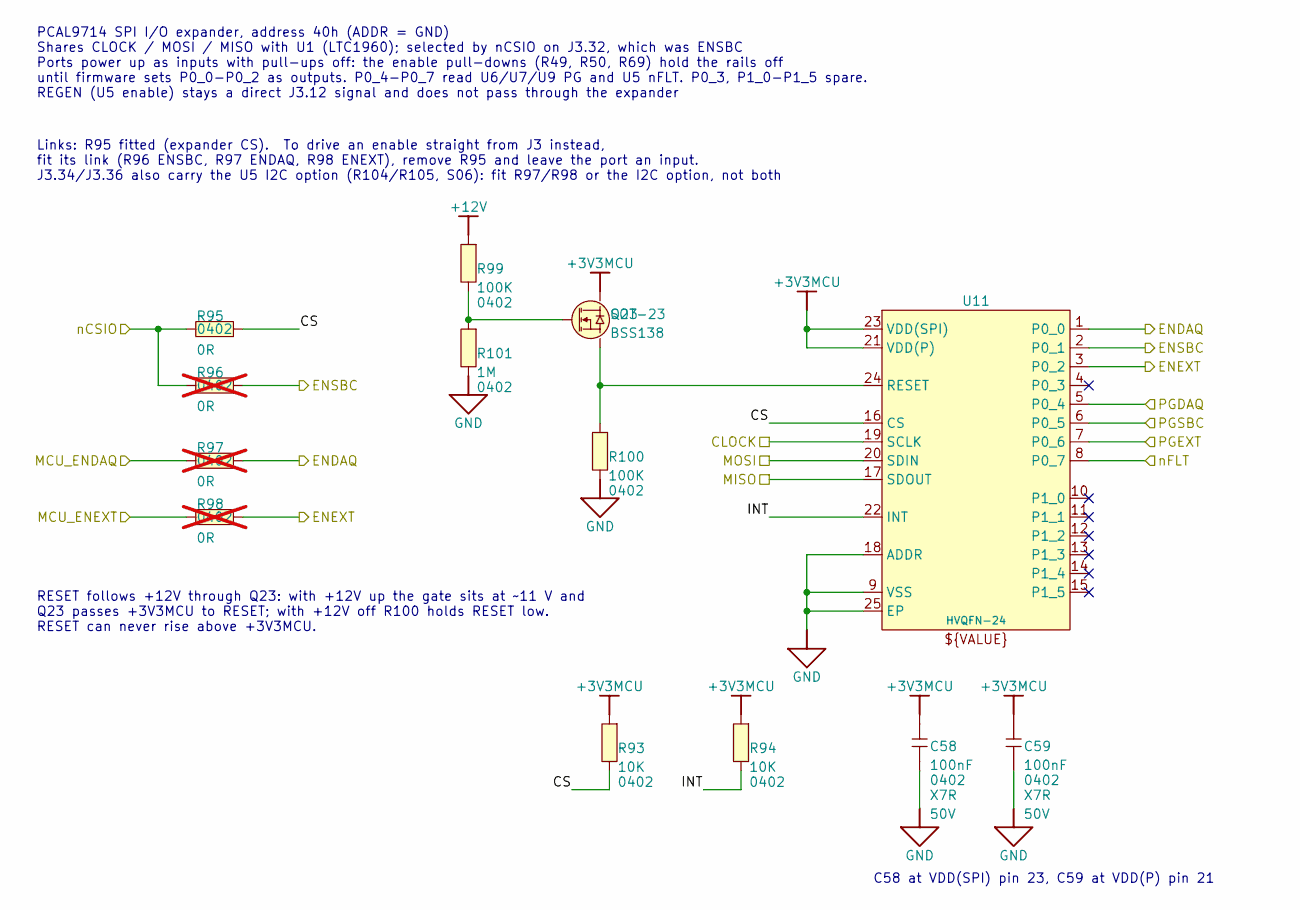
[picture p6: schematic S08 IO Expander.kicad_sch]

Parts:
C58, C59: 100nF; C_0402_1005Metric; VOLTAGE 50V; MANUFACTURER_PN CC0402KPX7R9BB104
Q23: BSS138; SOT-23; MANUFACTURER_PN BSS138
R93, R94: 10K; R_0402_1005Metric; MANUFACTURER_PN ?
R95: 0R; R_0402_1005Metric; MANUFACTURER_PN ?
R96, R97, R98: 0R; R_0402_1005Metric; MANUFACTURER_PN ?; not fitted
R99, R100: 100K; R_0402_1005Metric; MANUFACTURER_PN ?
R101: 1M; R_0402_1005Metric; MANUFACTURER_PN ?
U11: PCAL9714; HVQFN-24-1EP_4x4mm_P0.5mm_EP2.6x2.6mm; MANUFACTURER_PN PCAL9714HNMP

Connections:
+3V3MCU: C58.2, C59.2, Q23.3 (D), R93.2, R94.2, U11.21 (VDD(P)), U11.23 (VDD(SPI)); also elsewhere on the board
+12V: R99.2; also elsewhere on the board
/CLOCK: U11.19 (SCLK); also elsewhere on the board
/ENDAQ: R97.2, U11.1 (P0_0); also elsewhere on the board
/ENEXT: R98.2, U11.3 (P0_2); also elsewhere on the board
/ENSBC: R96.2, U11.2 (P0_1); also elsewhere on the board
/MCU_ENDAQ: R97.1; also elsewhere on the board
/MCU_ENEXT: R98.1; also elsewhere on the board
/MISO: U11.17 (SDOUT); also elsewhere on the board
/MOSI: U11.20 (SDIN); also elsewhere on the board
/PGDAQ: U11.5 (P0_4); also elsewhere on the board
/PGEXT: U11.7 (P0_6); also elsewhere on the board
/PGSBC: U11.6 (P0_5); also elsewhere on the board
/S08 IO Expander/CS: R93.1, R95.2, U11.16 (CS)
/S08 IO Expander/INT: R94.1, U11.22 (INT)
/nCSIO: R95.1, R96.1; also elsewhere on the board
/nFLT: U11.8 (P0_7); also elsewhere on the board
GND: C58.1, C59.1, R100.1, R101.1, U11.9 (VSS), U11.18 (ADDR), U11.25 (EP); also elsewhere on the board
unnamed: Q23.1 (G), R99.1, R101.2
unnamed: Q23.2 (S), R100.2, U11.24 (RESET)

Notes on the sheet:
Links: R95 fitted (expander CS). To drive an enable straight from J3 instead, fit its link (R96 ENSBC, R97 ENDAQ, R98 ENEXT), remove R95 and leave the port an input. J3.34/J3.36 also carry the U5 I2C option (R104/R105, S06): fit R97/R98 or the I2C option, not both
RESET follows +12V through Q23: with +12V up the gate sits at ~11 V and Q23 passes +3V3MCU to RESET; with +12V off R100 holds RESET low. RESET can never rise above +3V3MCU.
C58 at VDD(SPI) pin 23, C59 at VDD(P) pin 21
PCAL9714 SPI I/O expander, address 40h (ADDR = GND) Shares CLOCK / MOSI / MISO with U1 (LTC1960); selected by nCSIO on J3.32, which was ENSBC Ports power up as inputs with pull-ups off: the enable pull-downs (R49, R50, R69) hold the rails off until firmware sets P0_0-P0_2 as outputs. P0_4-P0_7 read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

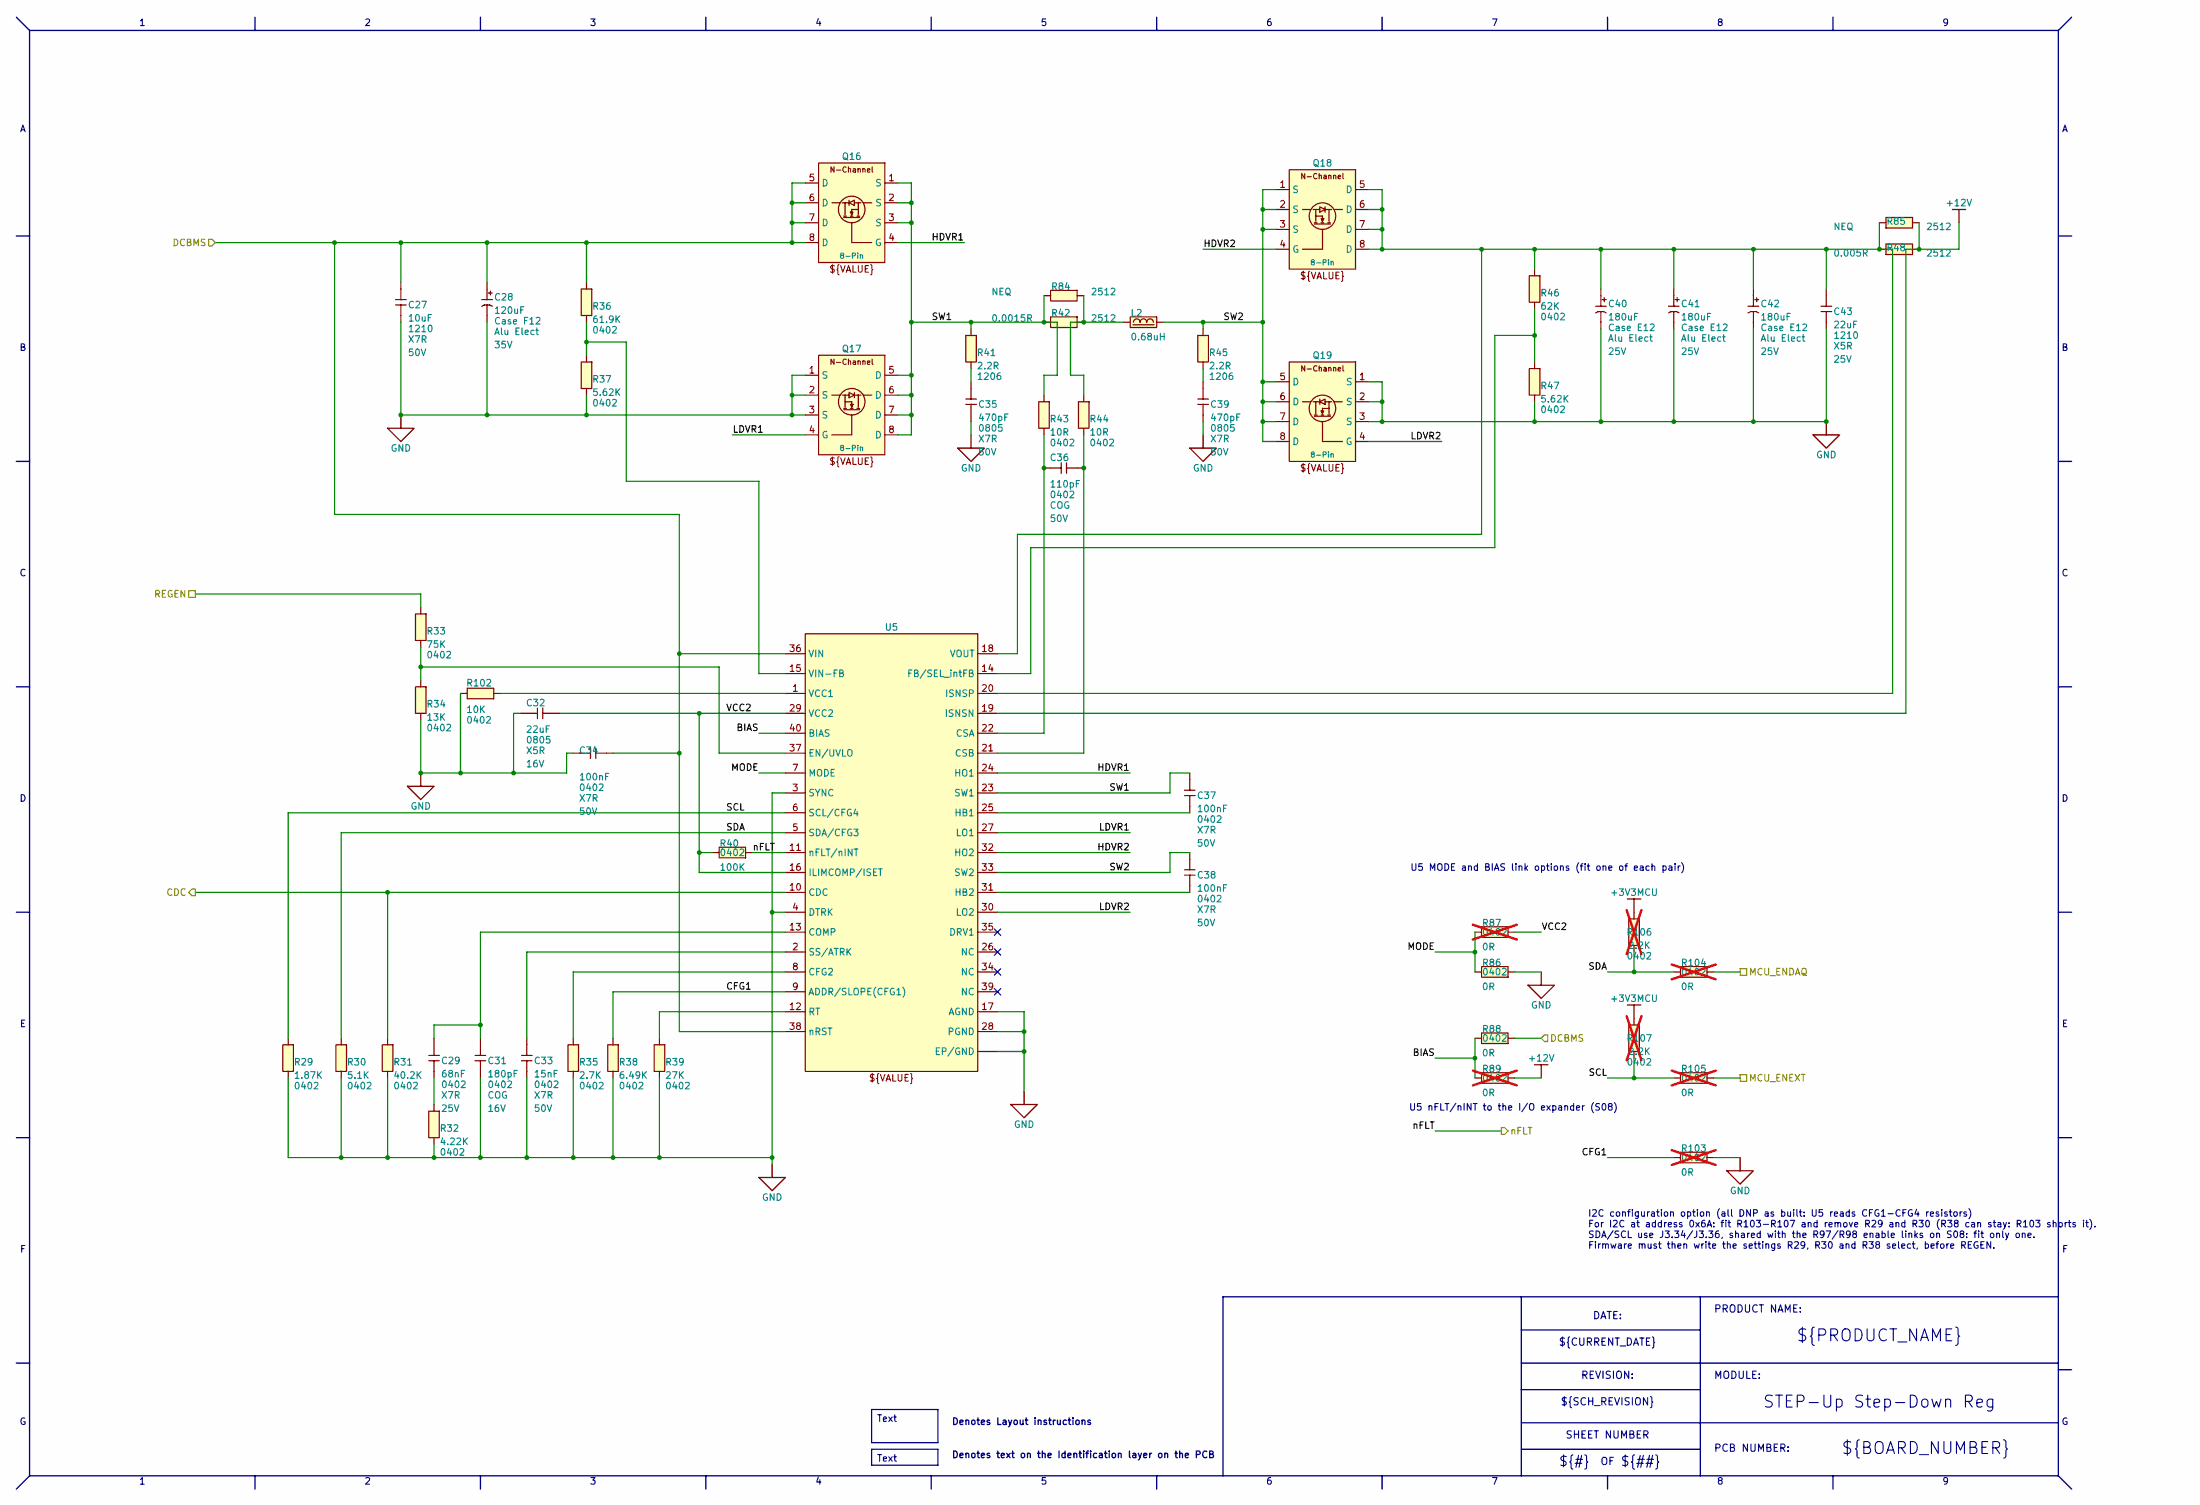
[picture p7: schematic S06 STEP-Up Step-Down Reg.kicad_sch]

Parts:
C27: 10uF; C_1210_3225Metric; VOLTAGE 50V; MANUFACTURER_PN GRM32ER71H106KA12L
C28: 120uF; CAP Panasonic CASE-F12; VOLTAGE 35V; MANUFACTURER_PN 35SVPF120M
C29: 68nF; C_0402_1005Metric; VOLTAGE 25V
C31: 180pF; C_0402_1005Metric; VOLTAGE 16V
C32: 22uF; C_0805_2012Metric; VOLTAGE 16V; MANUFACTURER_PN GRM21BR61C226ME44L
C33: 15nF; C_0402_1005Metric; VOLTAGE 50V
C34, C37, C38: 100nF; C_0402_1005Metric; VOLTAGE 50V; MANUFACTURER_PN CC0402KPX7R9BB104
C35: 470pF; C_0805_2012Metric; VOLTAGE 50V
C36: 110pF; C_0402_1005Metric; VOLTAGE 50V
C39: 1nF; C_0805_2012Metric; VOLTAGE 50V
C40, C41, C42: 180uF; CAP Panasonic CASE-E12; VOLTAGE 25V; MANUFACTURER_PN 25SVPF180M
C43: 22uF; C_1210_3225Metric; VOLTAGE 25V
L2: 0.68uH; IND COILCRAFT XAL8080; MANUFACTURER_PN XAL8080-681MEB
Q16, Q19: IAUCN04S7L019; PG-TDSON-8-33 B6.44 x 5.15 H1.0 P1.27 8-Pin EP; MANUFACTURER_PN PG-TDSON-8-33
Q17: IAUCN04S7L028; PG-TDSON-8-33 B6.44 x 5.15 H1.0 P1.27 8-Pin EP; MANUFACTURER_PN PG-TDSON-8-33
Q18: CSD17304Q3; Power CSD17304Q3-8 B3.3 x 3.3 P0.65 Tab 8-Pin EP1.75 x 2.45; MANUFACTURER_PN CSD17304Q3
R29: 1.87K; R_0402_1005Metric
R30: 5.1K; R_0402_1005Metric; MANUFACTURER_PN ?
R31: 40.2K; R_0402_1005Metric; MANUFACTURER_PN ?
R32: 4.22K; R_0402_1005Metric
R33: 75K; R_0402_1005Metric; MANUFACTURER_PN ?
R34: 13K; R_0402_1005Metric
R35: 2.7K; R_0402_1005Metric
R36: 61.9K; R_0402_1005Metric
R37, R47: 5.62K; R_0402_1005Metric
R38: 6.49K; R_0402_1005Metric
R39: 27K; R_0402_1005Metric; MANUFACTURER_PN ?
R40: 100K; R_0402_1005Metric; MANUFACTURER_PN ?
R41, R45: 2.2R; R_1206_3216Metric
R42: 0.0015R; R_2512_6332Metric; MANUFACTURER_PN WPB2512RL1M50FYR
R43, R44: 10R; R_0402_1005Metric; MANUFACTURER_PN ?
R46: 62K; R_0402_1005Metric
R48: 0.005R; R_2512_6332Metric; MANUFACTURER_PN CRE2512-FZ-R005E-3
R84, R85: NEQ; R_2512_6332Metric; MANUFACTURER_PN Res 2512
R86, R88: 0R; R_0402_1005Metric; MANUFACTURER_PN ?
R87, R89, R103, R104, R105: 0R; R_0402_1005Metric; MANUFACTURER_PN ?; not fitted
R102: 10K; R_0402_1005Metric; MANUFACTURER_PN ?
R106, R107: 2.2K; R_0402_1005Metric; MANUFACTURER_PN ?; not fitted
U5: LM51772RHAR; QFN B6x6 P0-5 40-Pin EP; MANUFACTURER_PN LM51772RHAR

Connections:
+3V3MCU: R106.2, R107.2; also elsewhere on the board
+12V: R48.1, R85.1, R89.2, U5.19 (ISNSN); also elsewhere on the board
/CDC: R31.2, U5.10 (CDC); also elsewhere on the board
/DCBMS: C27.2, C28.1 (+), C34.1, Q16.5 (D), Q16.6 (D), Q16.7 (D), Q16.8 (D), R36.2, R88.2, U5.36 (VIN), U5.38 (nRST); also elsewhere on the board
/MCU_ENDAQ: R104.2; also elsewhere on the board
/MCU_ENEXT: R105.2; also elsewhere on the board
/REGEN: R33.2; also elsewhere on the board
/S06 STEP-Up Step-Down Reg/BIAS: R88.1, R89.1, U5.40 (BIAS)
/S06 STEP-Up Step-Down Reg/CFG1: R38.2, R103.1, U5.9 (ADDR/SLOPE(CFG1))
/S06 STEP-Up Step-Down Reg/HDVR1: Q16.4 (G), U5.24 (HO1)
/S06 STEP-Up Step-Down Reg/HDVR2: Q18.4 (G), U5.32 (HO2)
/S06 STEP-Up Step-Down Reg/LDVR1: Q17.4 (G), U5.27 (LO1)
/S06 STEP-Up Step-Down Reg/LDVR2: Q19.4 (G), U5.30 (LO2)
/S06 STEP-Up Step-Down Reg/MODE: R86.1, R87.1, U5.7 (MODE)
/S06 STEP-Up Step-Down Reg/SCL: R29.2, R105.1, R107.1, U5.6 (SCL/CFG4)
/S06 STEP-Up Step-Down Reg/SDA: R30.2, R104.1, R106.1, U5.5 (SDA/CFG3)
/S06 STEP-Up Step-Down Reg/SW1: C37.2, Q16.1 (S), Q16.2 (S), Q16.3 (S), Q17.5 (D), Q17.6 (D), Q17.7 (D), Q17.8 (D), R41.2, R42.1, R43.2, R84.1, U5.23 (SW1)
/S06 STEP-Up Step-Down Reg/SW2: C38.2, L2.2, Q18.1 (S), Q18.2 (S), Q18.3 (S), Q19.5 (D), Q19.6 (D), Q19.7 (D), Q19.8 (D), R45.2, U5.33 (SW2)
/S06 STEP-Up Step-Down Reg/VCC2: C32.2, R40.1, R87.2, U5.16 (ILIMCOMP/ISET), U5.29 (VCC2)
/nFLT: R40.2, U5.11 (nFLT/nINT); also elsewhere on the board
GND: C27.1, C28.2 (-), C31.1, C32.1, C33.1, C34.2, C35.1, C39.1, C40.2 (-), C41.2 (-), C42.2 (-), C43.1, Q17.1 (S), Q17.2 (S), Q17.3 (S), Q19.1 (S), Q19.2 (S), Q19.3 (S), R29.1, R30.1, R31.1, R32.1, R34.1, R35.1, R37.1, R38.1, R39.1, R47.1, R86.2, R102.1, R103.2, U5.3 (SYNC), U5.4 (DTRK), U5.17 (AGND), U5.28 (PGND), U5.41 (EP/GND); also elsewhere on the board
unnamed: C29.1, R32.2
unnamed: C35.2, R41.1
unnamed: C39.2, R45.1
unnamed: C40.1 (+), C41.1 (+), C42.1 (+), C43.2, Q18.5 (D), Q18.6 (D), Q18.7 (D), Q18.8 (D), R46.2, R48.2, R85.2, U5.18 (VOUT), U5.20 (ISNSP)
unnamed: L2.1, R42.2, R44.2, R84.2
unnamed: R35.2, U5.8 (CFG2)
unnamed: C29.2, C31.2, U5.13 (COMP)
unnamed: C36.1, R43.1, U5.22 (CSA)
unnamed: C36.2, R44.1, U5.21 (CSB)
unnamed: R33.1, R34.2, U5.37 (EN/UVLO)
unnamed: R46.1, R47.2, U5.14 (FB/SEL_intFB)
unnamed: C37.1, U5.25 (HB1)
unnamed: C38.1, U5.31 (HB2)
unnamed: R39.2, U5.12 (RT)
unnamed: C33.2, U5.2 (SS/ATRK)
unnamed: R102.2, U5.1 (VCC1)
unnamed: R36.1, R37.2, U5.15 (VIN-FB)

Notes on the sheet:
DATE:
PCB NUMBER:
U5 nFLT/nINT to the I/O expander (S08)
Denotes text on the Identification layer on the PCB
SHEET NUMBER
PRODUCT NAME:
REVISION:
${##}
${BOARD_NUMBER}
I2C configuration option (all DNP as built: U5 reads CFG1-CFG4 resistors) For I2C at address 0x6A: fit R103-R107 and remove R29 and R30 (R38 can stay: R103 shorts it). SDA/SCL use J3.34/J3.36, shared with the R97/R98 enable links on S08: fit only one. Firmware must then write the settings R29, R30 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
${PRODUCT_NAME}
Denotes Layout instructions
${CURRENT_DATE}
MODULE:
${SCH_REVISION}
STEP-Up Step-Down Reg
U5 MODE and BIAS link options (fit one of each pair)
${#}
Text

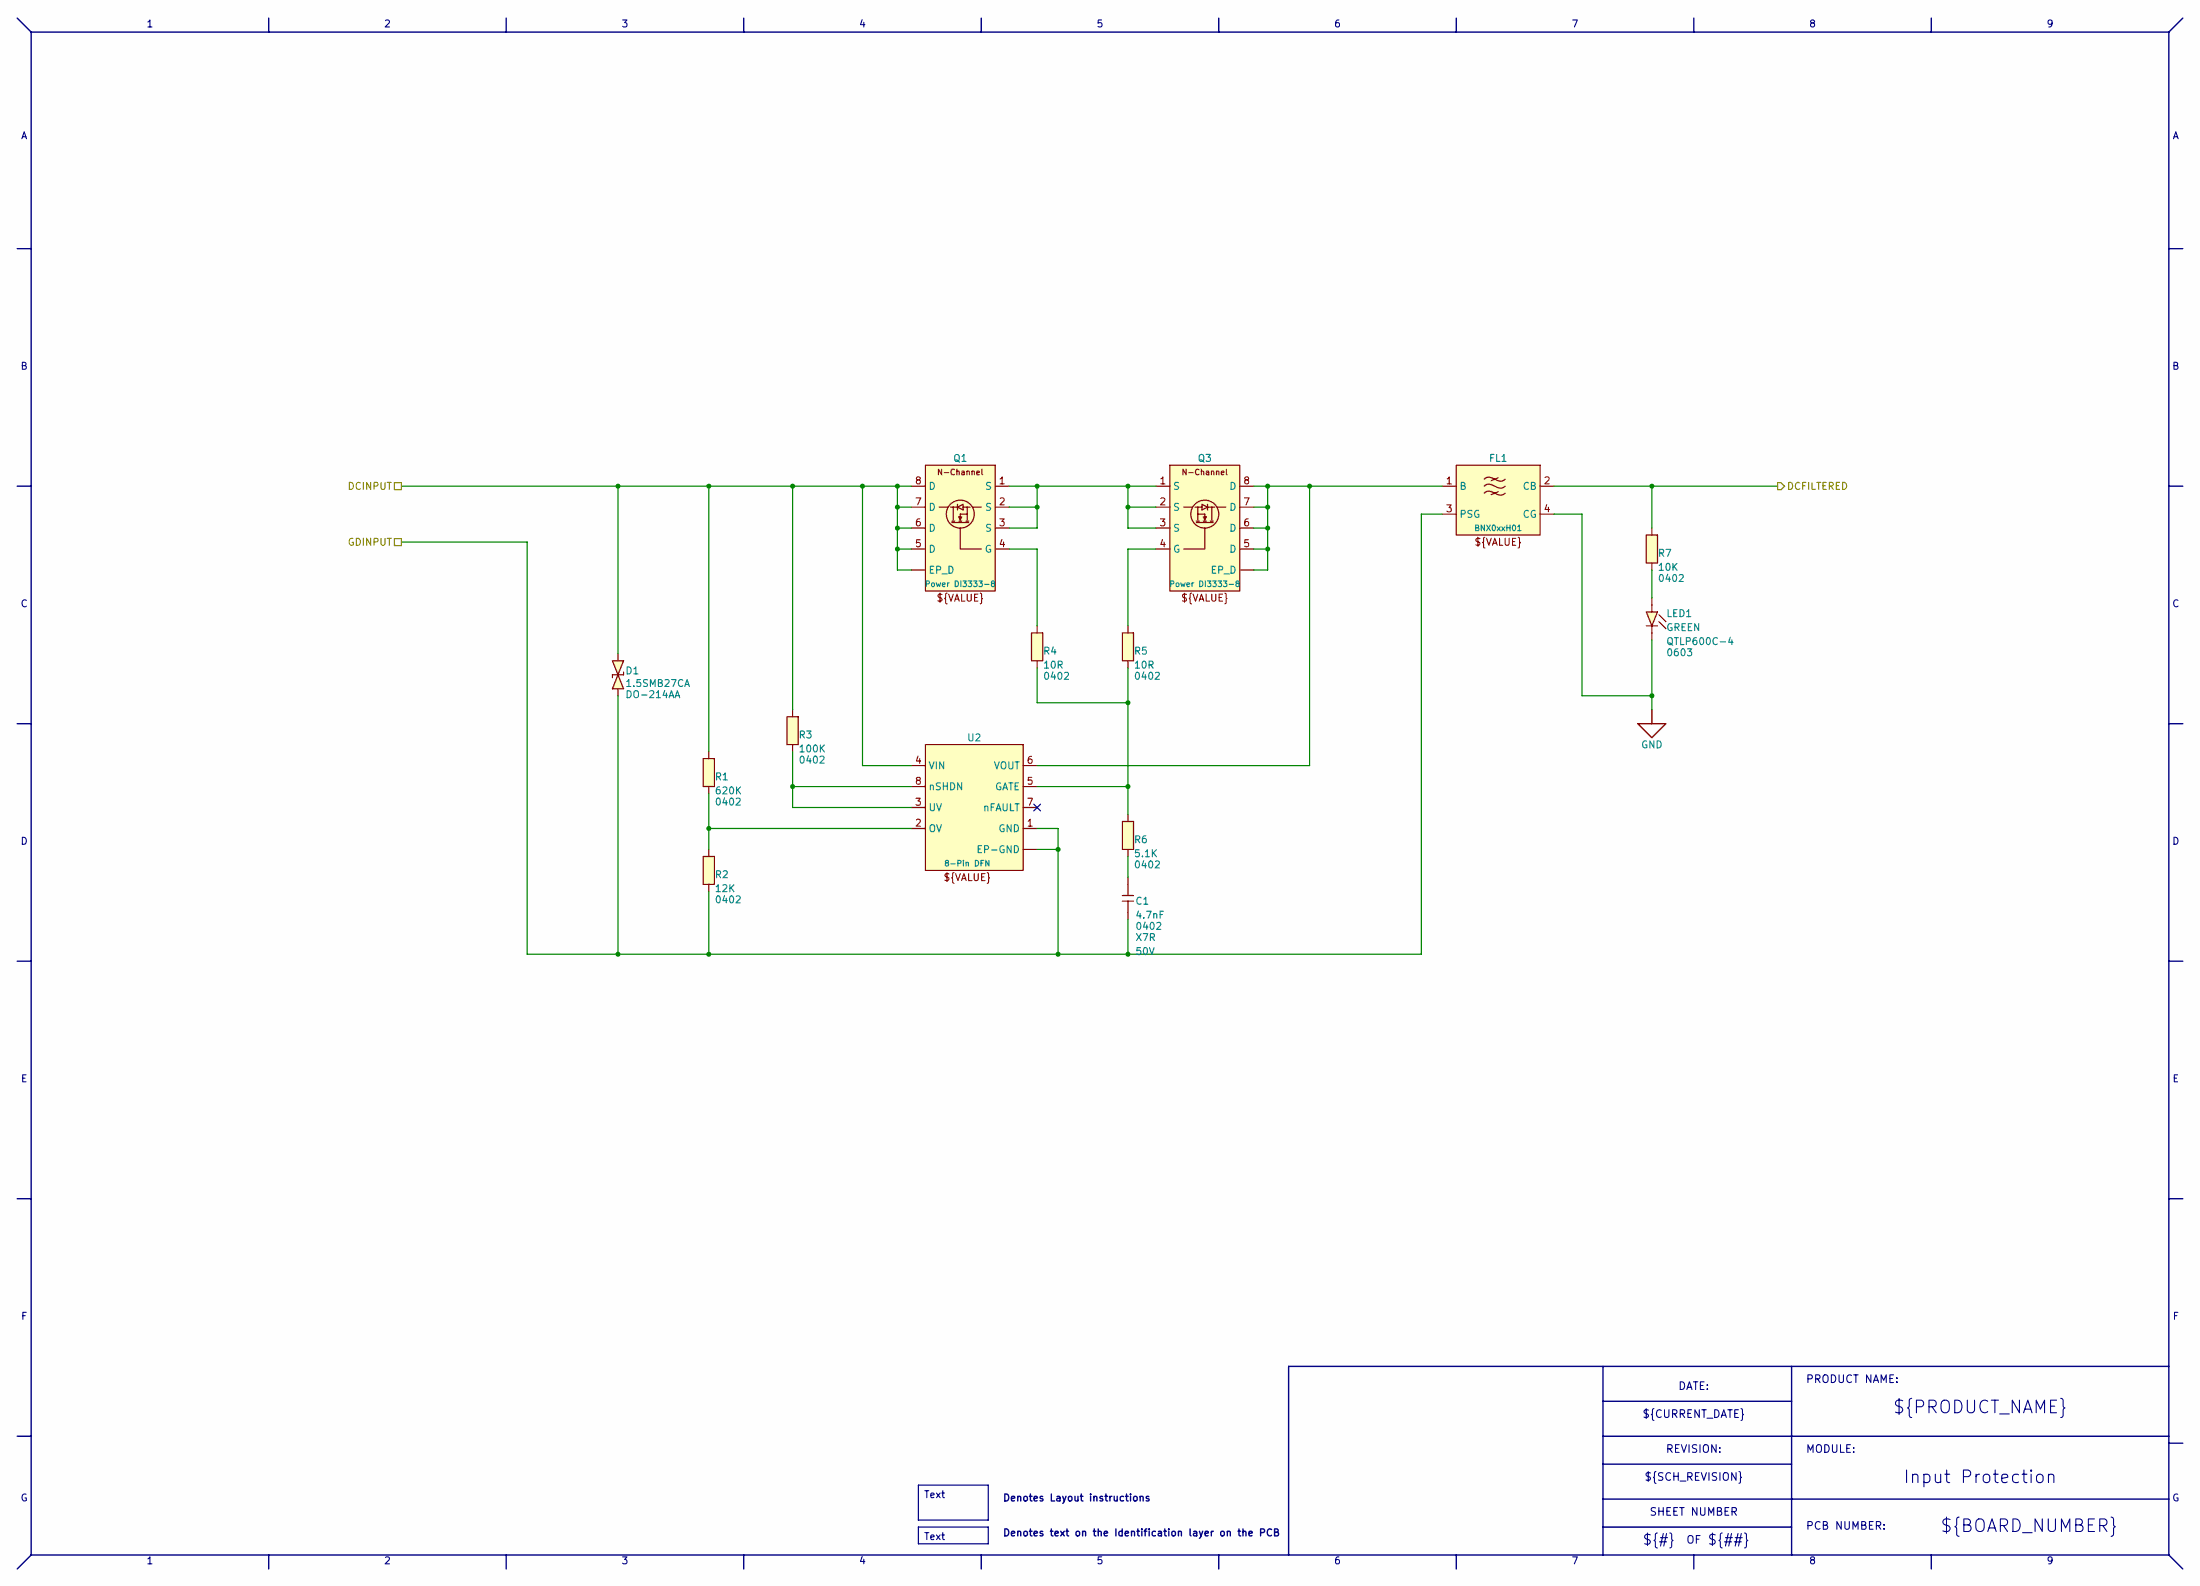
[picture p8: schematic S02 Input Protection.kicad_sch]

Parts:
C1: 4.7nF; C_0402_1005Metric; VOLTAGE 50V
D1: SMBJ26CA; Diode DO-214AA SMB Not-Pol; MANUFACTURER_PN SMBJ26CA
FL1: BNX024H01L; FILTER BNX0XXH01; MANUFACTURER_PN BNX024H01L
LED1: QTLP600C-4; LED 0603 H0-7 (C); MANUFACTURER_PN QTLP600C-4
Q1, Q3: DMT6007LFGQ-7; Power DI3333-8 B3.3 x 3.3 P0.65 Tab 8-Pin; MANUFACTURER_PN DMT6007LFGQ-7
R1: 619K; R_0402_1005Metric
R2: 12K; R_0402_1005Metric; MANUFACTURER_PN ?
R3: 100K; R_0402_1005Metric; MANUFACTURER_PN ?
R4, R5: 10R; R_0402_1005Metric
R6: 5.1K; R_0402_1005Metric; MANUFACTURER_PN ?
R7: 10K; R_0402_1005Metric; MANUFACTURER_PN ?
U2: LTC4365; DFN B2.0 x 3.0 x 0.75 P0.5 8-Pin EP; MANUFACTURER_PN LTC4365IDDB

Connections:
/DCFILTERED: FL1.2 (CB), R7.2; also elsewhere on the board
/DCINPUT: D1.2 (A), Q1.5 (D), Q1.6 (D), Q1.7 (D), Q1.8 (D), Q1.9 (EP_D), R1.2, R3.2, U2.4 (VIN); also elsewhere on the board
/GDINPUT: C1.1, D1.1 (C), FL1.3 (PSG), R2.1, U2.1 (GND), U2.9 (EP-GND); also elsewhere on the board
GND: FL1.4 (CG), LED1.1 (C); also elsewhere on the board
unnamed: C1.2, R6.1
unnamed: FL1.1 (B), Q3.5 (D), Q3.6 (D), Q3.7 (D), Q3.8 (D), Q3.9 (EP_D), U2.6 (VOUT)
unnamed: LED1.2 (A), R7.1
unnamed: Q1.4 (G), R4.2
unnamed: Q1.1 (S), Q1.2 (S), Q1.3 (S), Q3.1 (S), Q3.2 (S), Q3.3 (S)
unnamed: Q3.4 (G), R5.2
unnamed: R4.1, R5.1, R6.2, U2.5 (GATE)
unnamed: R1.1, R2.2, U2.2 (OV)
unnamed: R3.1, U2.3 (UV), U2.8 (nSHDN)

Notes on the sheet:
Denotes Layout instructions
${PRODUCT_NAME}
${#}
Denotes text on the Identification layer on the PCB
REVISION:
${BOARD_NUMBER}
PRODUCT NAME:
DATE:
${CURRENT_DATE}
MODULE:
${##}
Input Protection
SHEET NUMBER
PCB NUMBER:
${SCH_REVISION}
Text

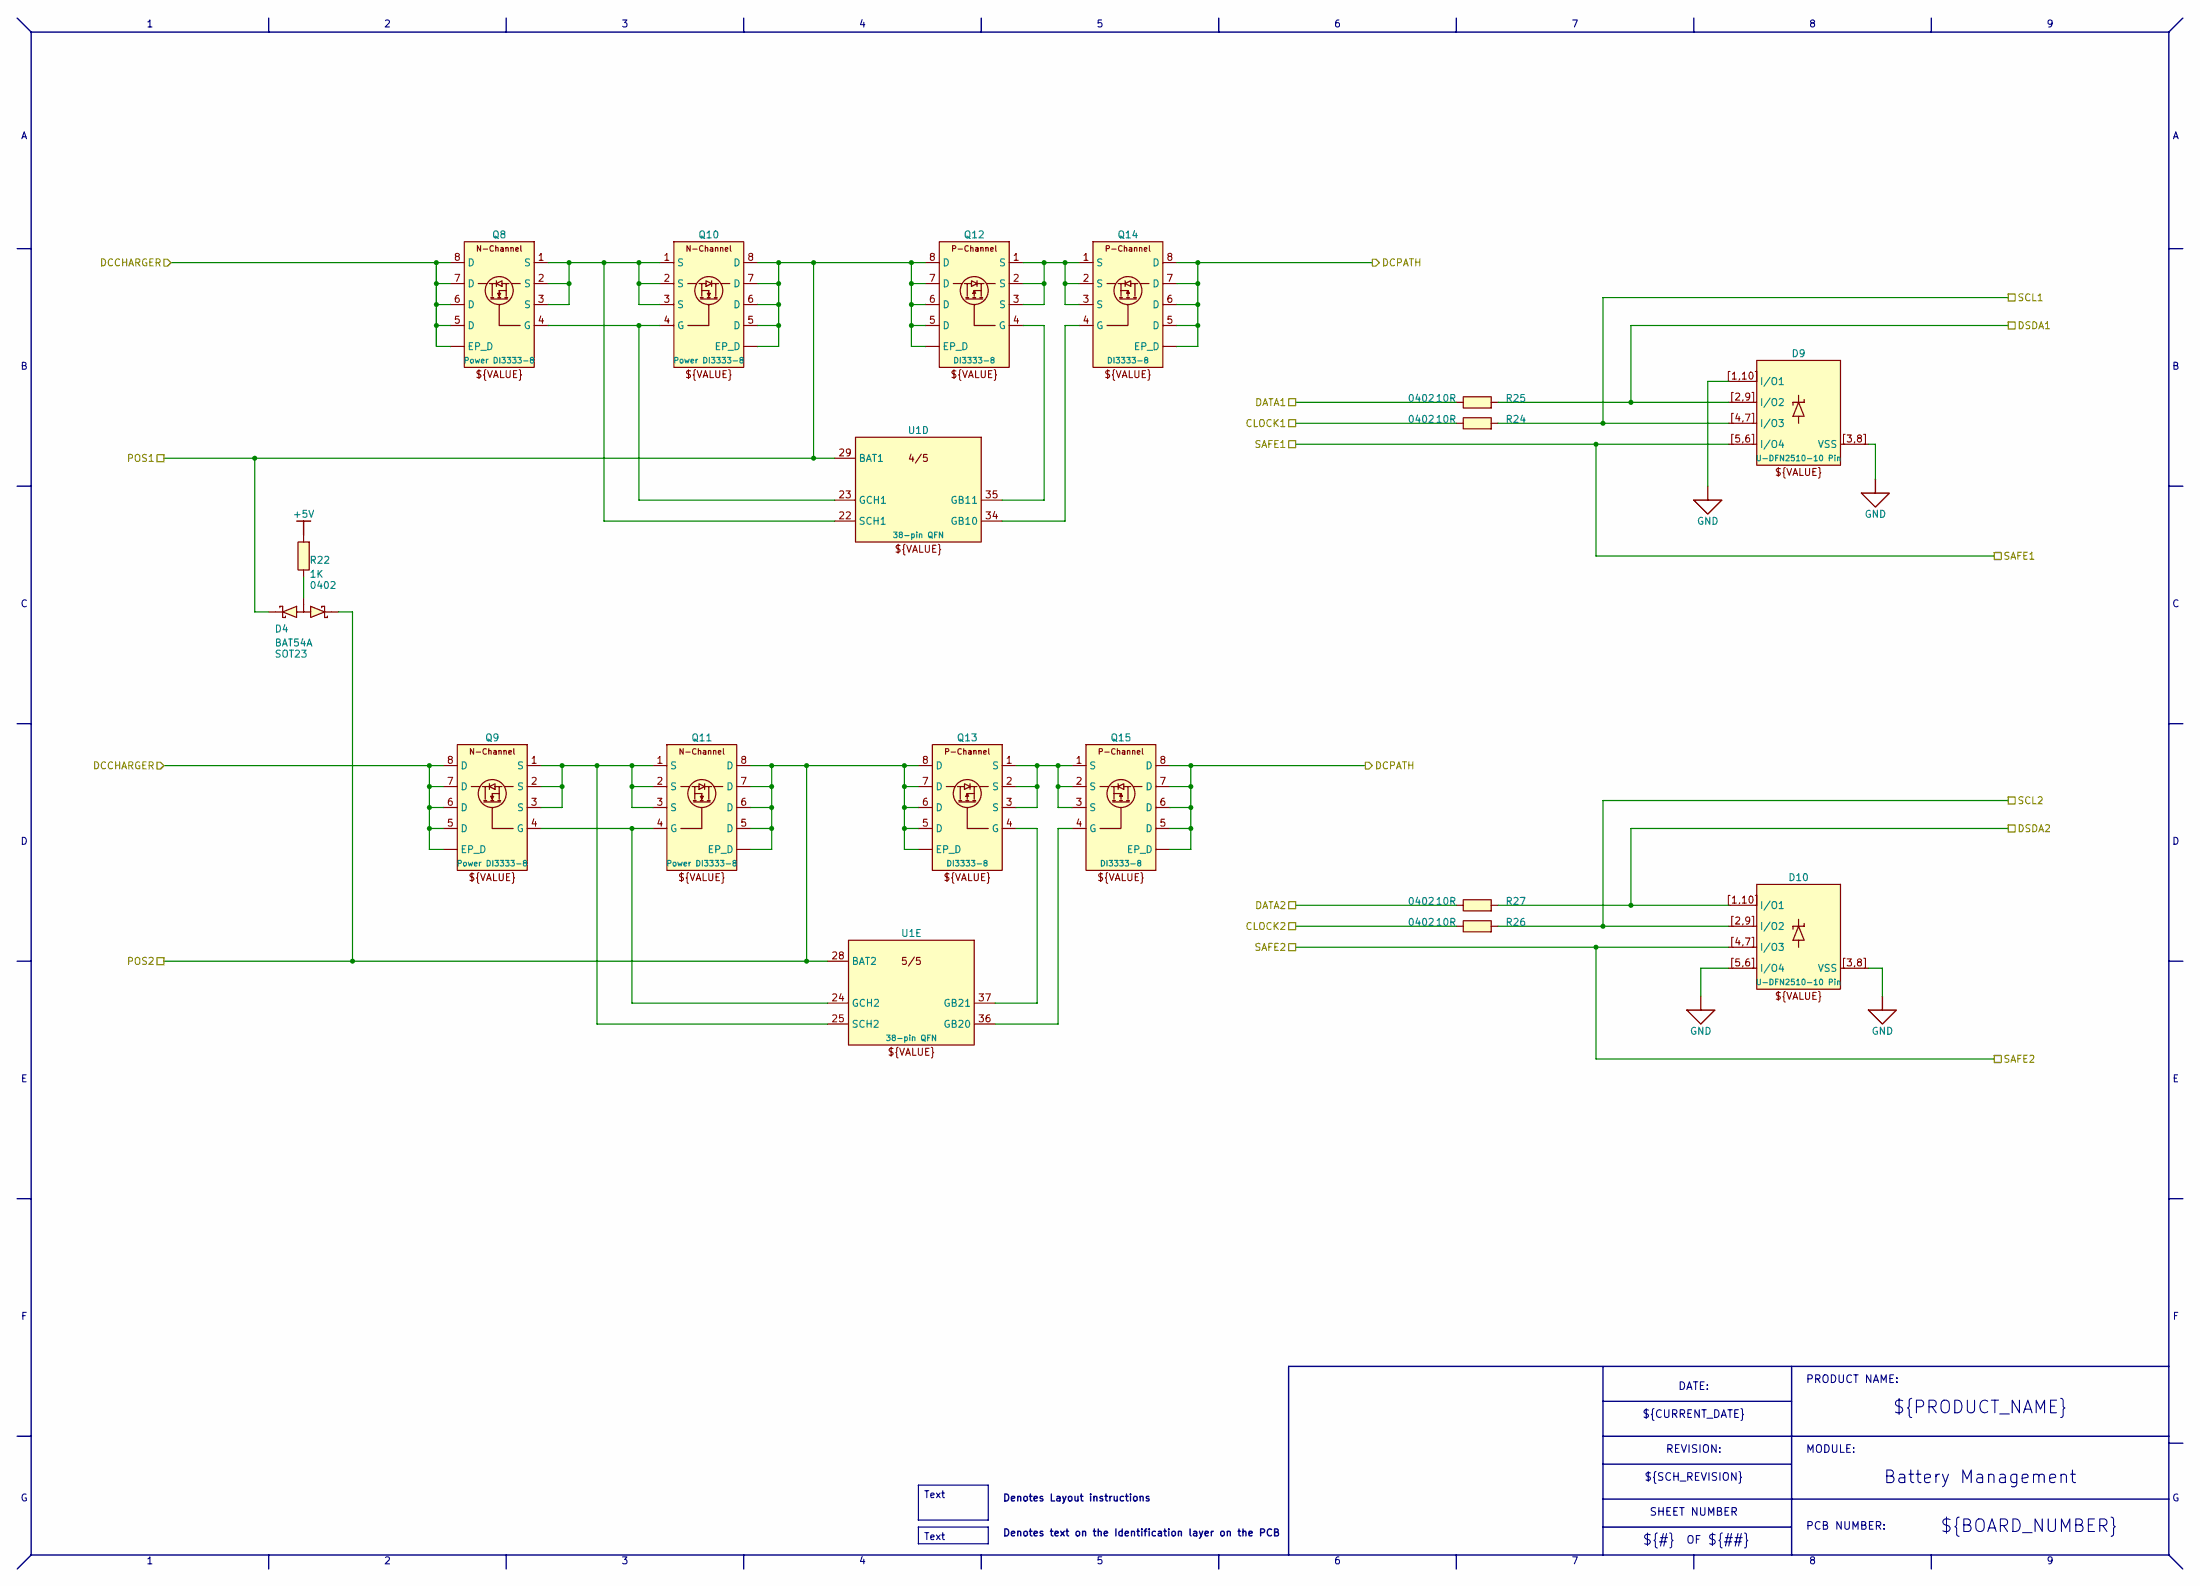
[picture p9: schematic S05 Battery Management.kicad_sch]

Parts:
D4: BAT54A; SOT-23 3-Pin; MANUFACTURER_PN BAT54A
D9, D10: DT1240V3-04LP; U-DFN2510-10 DIODE INC; MANUFACTURER_PN DT1240V3-04LP
Q8, Q9, Q10, Q11: DMT4011LFG; Power DI3333-8 B3.3 x 3.3 P0.65 Tab 8-Pin; MANUFACTURER_PN DMT4011LFG
Q12, Q13, Q14, Q15: DMP3018SFV; Power DI3333-8 B3.3 x 3.3 P0.65 Tab 8-Pin; MANUFACTURER_PN DMP3018SFV
R22: 1K; R_0402_1005Metric; MANUFACTURER_PN ?
R24, R25, R26, R27: 10R; R_0402_1005Metric
U1: LTC1960; QFN B5x7 P0-5 38-Pin EP; MANUFACTURER_PN LTC1960CUHF

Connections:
+5V: R22.2; also elsewhere on the board
/CLOCK1: R24.1; also elsewhere on the board
/CLOCK2: R26.1; also elsewhere on the board
/DATA1: R25.1; also elsewhere on the board
/DATA2: R27.1; also elsewhere on the board
/DCCHARGER: Q8.5 (D), Q8.6 (D), Q8.7 (D), Q8.8 (D), Q8.9 (EP_D), Q9.5 (D), Q9.6 (D), Q9.7 (D), Q9.8 (D), Q9.9 (EP_D); also elsewhere on the board
/DCPATH: Q14.5 (D), Q14.6 (D), Q14.7 (D), Q14.8 (D), Q14.9 (EP_D), Q15.5 (D), Q15.6 (D), Q15.7 (D), Q15.8 (D), Q15.9 (EP_D); also elsewhere on the board
/DSDA1: D9.2 (I/O2), D9.9 (I/O2), D9.[2,9] (I/O2), R25.2; also elsewhere on the board
/DSDA2: D10.1 (I/O1), D10.10 (I/O1), D10.[1,10] (I/O1), R27.2; also elsewhere on the board
/POS1: D4.1 (2C), Q10.5 (D), Q10.6 (D), Q10.7 (D), Q10.8 (D), Q10.9 (EP_D), Q12.5 (D), Q12.6 (D), Q12.7 (D), Q12.8 (D), Q12.9 (EP_D), U1.29 (BAT1); also elsewhere on the board
/POS2: D4.2 (1C), Q11.5 (D), Q11.6 (D), Q11.7 (D), Q11.8 (D), Q11.9 (EP_D), Q13.5 (D), Q13.6 (D), Q13.7 (D), Q13.8 (D), Q13.9 (EP_D), U1.28 (BAT2); also elsewhere on the board
/SAFE1: D9.5 (I/O4), D9.6 (I/O4); also elsewhere on the board
/SAFE2: D10.4 (I/O3), D10.7 (I/O3); also elsewhere on the board
/SCL1: D9.4 (I/O3), D9.7 (I/O3), D9.[4,7] (I/O3), R24.2; also elsewhere on the board
/SCL2: D10.2 (I/O2), D10.9 (I/O2), D10.[2,9] (I/O2), R26.2; also elsewhere on the board
GND: D9.1 (I/O1), D9.3 (VSS), D9.8 (VSS), D9.10 (I/O1), D10.3 (VSS), D10.5 (I/O4), D10.6 (I/O4), D10.8 (VSS); also elsewhere on the board
unnamed: D4.3 (A), R22.1
unnamed: Q8.4 (G), Q10.4 (G), U1.23 (GCH1)
unnamed: Q9.4 (G), Q11.4 (G), U1.24 (GCH2)
unnamed: Q12.4 (G), U1.35 (GB11)
unnamed: Q12.1 (S), Q12.2 (S), Q12.3 (S), Q14.1 (S), Q14.2 (S), Q14.3 (S)
unnamed: Q13.4 (G), U1.37 (GB21)
unnamed: Q13.1 (S), Q13.2 (S), Q13.3 (S), Q15.1 (S), Q15.2 (S), Q15.3 (S)
unnamed: Q14.4 (G), U1.34 (GB10)
unnamed: Q15.4 (G), U1.36 (GB20)
unnamed: Q8.1 (S), Q8.2 (S), Q8.3 (S), Q10.1 (S), Q10.2 (S), Q10.3 (S), U1.22 (SCH1)
unnamed: Q9.1 (S), Q9.2 (S), Q9.3 (S), Q11.1 (S), Q11.2 (S), Q11.3 (S), U1.25 (SCH2)

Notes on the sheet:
MODULE:
SHEET NUMBER
REVISION:
PRODUCT NAME:
${BOARD_NUMBER}
${#}
Denotes Layout instructions
${CURRENT_DATE}
DATE:
${##}
Denotes text on the Identification layer on the PCB
PCB NUMBER:
Battery Management
${SCH_REVISION}
${PRODUCT_NAME}
Text

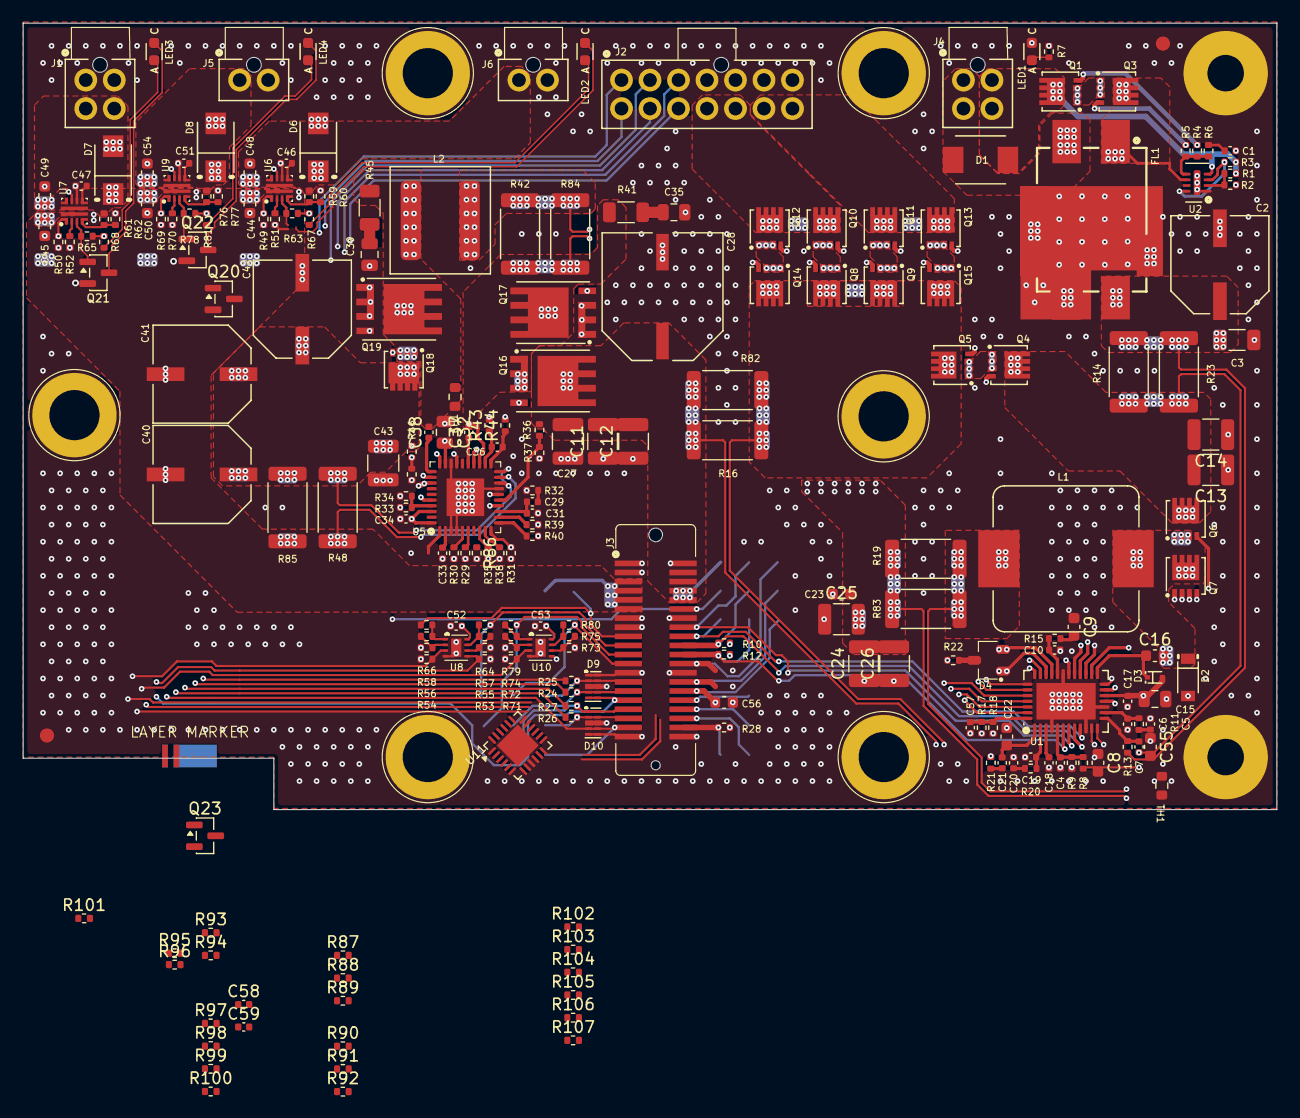
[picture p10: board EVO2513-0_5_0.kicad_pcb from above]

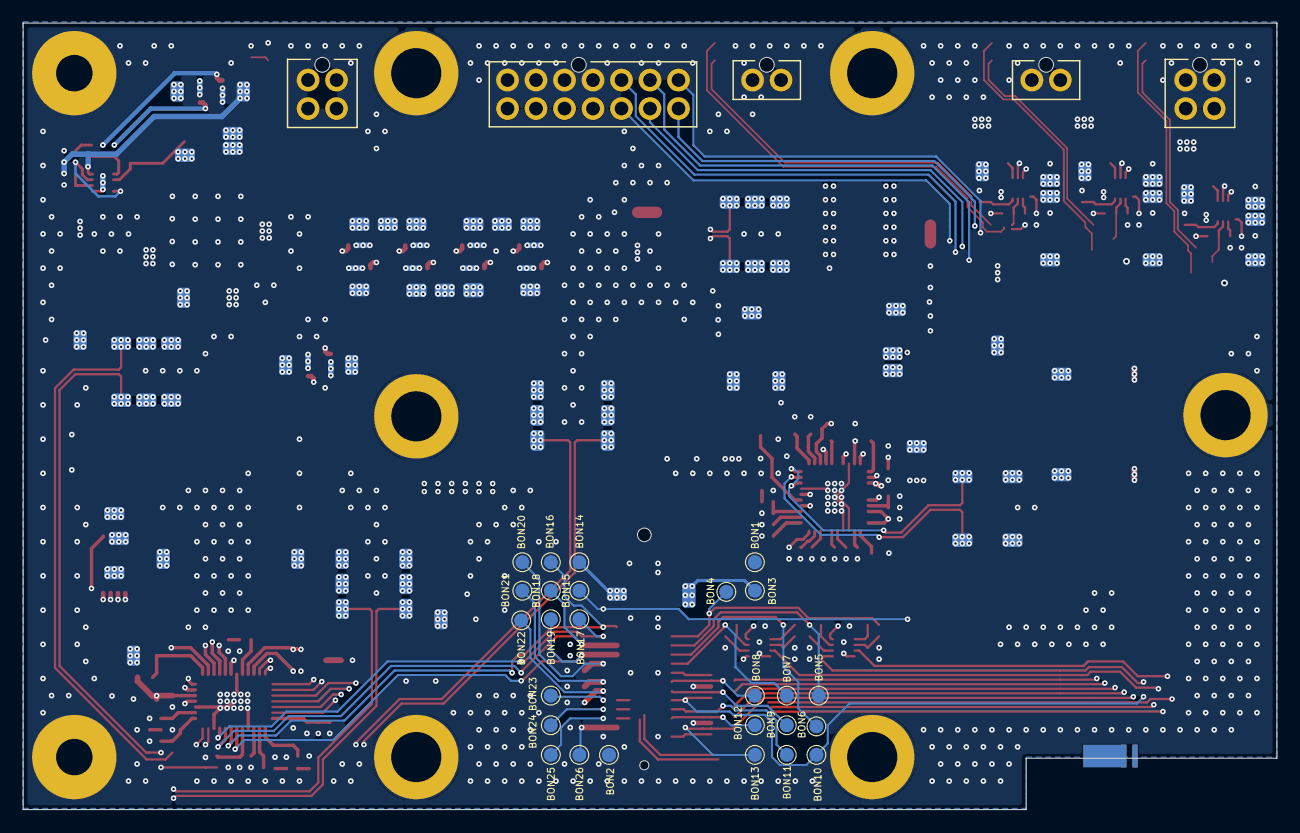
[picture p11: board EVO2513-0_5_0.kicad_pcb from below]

Board: 8 copper layers, 110.0 x 69.0 mm, 256 parts (26 on the bottom side), 148 nets.

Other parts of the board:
H1, H2: (no value)

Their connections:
GND: H1.MNT 3.2, H2.MNT 3.2; also elsewhere on the board

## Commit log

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2026-10-02 Replace ${ALTIUM_VALUE} placeholders with literal values
    The Altium import left every symbol's Value field as ${ALTIUM_VALUE},
    resolved through a per-symbol ALTIUM_VALUE field. Copy that field's
    contents into Value (209 symbols) so values are visible in tools and
    exports that don't resolve the variable. All values match the PCB.
    The 26 BON pogo test pads had no ALTIUM_VALUE field; set them to POGO-1.
    [EVO2513-0_5_0.kicad_sch, S02 Input Protection.kicad_sch, S03 BMS Input and Output Monitor.kicad_sch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]
2026-10-02 Fix footprint name case mismatches between schematic and PCB
    The Altium import wrote 12 symbol Footprint fields with different
    letter case from the footprint actually placed on the PCB and stored
    in the project library (e.g. "Ind Coilcraft XAL8080" vs
    "IND COILCRAFT XAL8080"). Library lookup is case-sensitive, so these
    footprints could not be found when updating the PCB from the schematic.
    Point each field at the footprint the PCB uses: J2, J5, J6, M2-M6,
    FL1, D9, D10 and L2. The PCB is unchanged.
    [EVO2513-0_5_0.kicad_sch, S02 Input Protection.kicad_sch, S05 Battery Management.kicad_sch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]
2026-10-02 Rename imported FOOTPRINT field to ALTIUM_FOOTPRINT
    The Altium import added a user field named FOOTPRINT holding the bare
    package name (e.g. "0402", "SMA"). KiCad matches field names
    case-insensitively, so it overrode the real Footprint field: Update PCB
    from Schematic looked up footprints like "0402" and failed for 222
    parts, and saving the schematic replaced each library footprint link
    with the package name.
    Rename the field on all 237 symbols so the package name is kept but no
    longer collides with Footprint.
    [EVO2513-0_5_0.kicad_sch, S02 Input Protection.kicad_sch, S03 BMS Input and Output Monitor.kicad_sch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]
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2026-10-02 Update PCB from schematic
    Run Update PCB from Schematic now that footprints, cross-sheet nets and
    power symbol annotation are fixed. The update completed with no errors.
    - Re-link all 229 footprints to their schematic symbols
    - Rename 108 nets to KiCad names (e.g. NetR1_2 -> Net-(R1-Pad2), sheet
    prefixes on single-sheet labels, unconnected-* for NC pins); no nets
    are split or merged, and all 147 match the schematic netlist
    - Copy symbol fields to footprints; BON pads take the value POGO-1
    Footprint placement, pads, tracks, vias, zones and board graphics are
    unchanged.
    [EVO2513-0_5_0.kicad_pcb]
2026-10-02 Replace Altium =Value and =FootPrint special strings
    44 embedded library symbols (connectors, FETs, ICs) drew the Altium
    special strings "=Value" and "=FootPrint" as graphic text, which KiCad
    showed literally.
    - "=Value" becomes ${VALUE}. The Value field is hidden on these parts,
    so the value isn't shown twice.
    - "=FootPrint" is removed from the symbol drawings. Instead, each of the
    49 placed units shows its own ALTIUM_FOOTPRINT field at the same
    position and font size. ERC does not resolve custom fields used in
    symbol body text, so ${ALTIUM_FOOTPRINT} there would be reported as
    an unresolved variable.
    Each part shows its value and package as in Altium, and ERC reports no
    new unr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
    [EVO2513-0_5_0.kicad_sch, S02 Input Protection.kicad_sch, S03 BMS Input and Output Monitor.kicad_sch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]
2026-10-02 Export embedded symbols to project symbol libraries
    The symbols' "Lattech Systems" library wasn't supplied, so each symbol
    existed only as copies embedded in the schematics, and ERC reported 336
    missing-library issues.
    Write the embedded symbols to two project libraries, keeping the
    library names the schematics already use, and register them in
    sym-lib-table:
    - EVO2513-0_5_0-lattech.kicad_sym (Lattech Systems): 96 symbols
    - EVO2513-0_5_0-altium-import.kicad_sym: 4 power symbols
    Some symbols had been embedded in several versions that differ only in
    rectangle corner order or drawing order. Use one definition for each,
    and point the 12 placements that used a numbered variant (_1, _2, ...)
    ba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
    [S02 Input Protection.kicad_sch, S03 BMS Input and Output Monitor.kicad_sch, S04 Charger Regulation.kicad_sch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]
2026-10-02 Use KiCad standard footprints for chip resistors and capacitors
    The imported Lattech R/C footprints have poor land patterns (the 0402s
    use 0.635 mm circular pads) and cause tombstoning in assembly. Replace
    all 139 chip resistors and capacitors with KiCad's standard IPC-7351
    nominal footprints:
    Res 0402/0603/1206/2512 -> Resistor_SMD:R_xxxx_xxxxMetric (87)
    Cap 0402/0603/0805/1206/1210 -> Capacitor_SMD:C_xxxx_xxxxMetric (52)
    Each part keeps its position, rotation, side, pad nets, schematic link
    and reference/value text placement. The pads are on the same axis with
    pad 1 on the same side, and every old pad centre lies inside the new
    pad, so existing tracks still connect. Zones are refille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
    [EVO2513-0_5_0.kicad_pcb, EVO2513-0_5_0.kicad_sch, S02 Input Protection.kicad_sch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]
2026-10-02 Fix PCB DRC issues from the import
    The GUI DRC reported 1195 violations. Most came from the import not
    carrying the Altium design rules across; the rest were import defects.
    - Design rules now match the Altium .PcbDoc: clearance, minimum track
    width and via annular ring 0.15 mm, minimum hole 0.15 mm, hole to
    hole 0.3 mm, and a custom rule (EVO2513-0_5_0.kicad_dru) for
    Altium's 0.3 mm "BON Pogo-1" clearance between test-point pads.
    Altium has no hole-to-copper rule, so KiCad's 0.25 mm check stays.
    - FL1's large ground land had no pad number, hence no net, so its 38
    GND stitching vias showed as shorts. It only touches the GND (pad 4)
    lands, so it is numbered 4 on the board and in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
    [EVO2513-0_5_0.kicad_pcb]
2026-10-02 Fix schematic ERC issues from the import
    ERC across all seven sheets reported 1481 issues from the import:
    - Every item sat 43 mil off KiCad's 50 mil connection grid in Y, so new
    wires would not snap to existing pins. Each sheet's contents are
    shifted 7 mil (0.1778 mm) onto the grid; the library symbol
    definitions are untouched and a uniform shift keeps every connection.
    A few wire corners on S06 were off grid on their own (at 6740 mil,
    7620 mil and y 3290 mil); they move to the nearest grid point, which
    removes two 10 mil stubs and moves #PWR065 with its wire.
    - Nine wires ran 1.27-2.54 mm past the label sitting on them (ID on S01;
    LDVR1/2 and HDVR1/2 on S06), leaving danglin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
    [EVO2513-0_5_0.kicad_pcb, EVO2513-0_5_0.kicad_sch, S02 Input Protection.kicad_sch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]
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2026-10-02 Link the sheets through hierarchical labels and sheet pins
    The 78 cross-sheet global labels on S01-S07 become hierarchical labels,
    and each sheet symbol on the root gets a pin per label name (71 pins).
    On the root, each pin connects through a short wire to a global label
    with the net name. Global labels there, rather than local ones, keep the
    35 net names free of a "/" sheet-path prefix, so the net classes and the
    board's nets are unchanged.
    Layout: S01 External Connectors on the left with its pins on the right
    edge; S02-S04 and S05-S07 in two columns with their pins on the left.
    The netlist is identical to before (229 components, 147 nets, same names
    and pins). kicad-cli ERC: 0 errors, 0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
    [EVO2513-0_5_0.kicad_sch, S01 External Connectors.kicad_sch, S02 Input Protection.kicad_sch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]
2026-10-02 Replace the root sheet's global labels with local labels
    The root sheet joined the sheet pins with 71 global labels. They are now
    local labels on short wire stubs, so the design has no global labels.
    Nets are named by their highest-level label, so the 35 cross-sheet nets
    now carry the root path: DCBMS becomes /DCBMS, POS1 becomes /POS1, and so
    on. The 16 net class patterns that named them, and the board's 1402 net
    references, are renamed to match. Connectivity is unchanged (147 nets,
    same pins), and every net keeps its net class.
    kicad-cli ERC: 0 errors, 0 warnings. DRC with schematic parity: 0 parity
    issues, 450 violations as before.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
    [EVO2513-0_5_0.kicad_pcb, EVO2513-0_5_0.kicad_sch]
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2026-10-02 Wire the root sheet links between S01-S04
    On the root sheet, S01 now wires directly to S02 (DCINPUT, GDINPUT) and
    S03 (CLOCK, MISO, MOSI, nCS, DCBMS), S02 to S03 (DCFILTERED) and S03 to
    S04 (DCSENSED), in place of label pairs. S03's DCFILTERED and DCSENSED
    pins move so the wires nest without crossing. Each wired net keeps a
    label, so net names are unchanged; the other links still use labels.
    Saving in KiCad also added show_name/do_not_autoplace to property fields
    on the sub-sheets, and set the IPC-2581 schematic revision to
    ${SCH_REVISION} and wire hop-overs on in the project settings.
    Netlist unchanged (147 nets, same names and pins). kicad-cli ERC: 0
    errors, 0 warnings.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
    [EVO2513-0_5_0.kicad_sch, S01 External Connectors.kicad_sch, S02 Input Protection.kicad_sch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]
2026-10-02 Apply the W16 review part, value and rating changes
    From the W16 schematic review (sections 1-3). None of these changes a
    connection; the board's copper is untouched.
    - Q1, Q3: DMT4011LFG 40 V -> DMT6007LFGQ-7 60 V (same PowerDI3333-8)
    - D1: 1.5SMB27CA -> SMBJ26CA, Littelfuse (42.1 V clamp; ST's clamps 53.5 V)
    - L1: 4.7 uH SRP1265A-4R7M -> 10 uH SRP1265A-100M (LTC1960 minimum)
    - C10: 100 nF 16 V -> 50 V CC0402KPX7R9BB104 (VPLUS ~23 V)
    - R54: 1 k -> 768R RC0402FR-07768RL; R22, R53, R71 stay 1 k
    - C16: 220 nF C0G 0805 (doesn't exist) -> X7R CC0805KFX7R9BB224
    - C39: 470 pF -> 1 nF (SW2 snubber)
    - C3, C11, C12, C55: 35 V -> 50 V; C44, C45, C48-C50, C54: 16 V -> 50 V
    (C7 stays 16 V: it sits ac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
    [EVO2513-0_5_0.kicad_pcb, S02 Input Protection.kicad_sch, S03 BMS Input and Output Monitor.kicad_sch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]
2026-10-02 Put U5 MODE and BIAS on 0R link options
    From the W16 review: U5 (LM51772) MODE should leave the VCC2 net and go to
    GND, and BIAS to +12V is still under review. Both are built as 0R 0402
    link pairs so either configuration can be fitted:
    - MODE (pin 7): R86 to GND fitted, R87 to VCC2/ILIMCOMP DNP (the old
    connection, forced PWM)
    - BIAS (pin 40): R88 to DCBMS fitted (the old connection), R89 to +12V DNP
    Pins 16 (ILIMCOMP) and 29 (VCC2) stay together, as the review requires;
    that net is now labelled VCC2. nRST stays on DCBMS. The links sit in the
    lower right of S06, joined to U5 by local labels. New "Resistor 0R 0402"
    symbol in the project library.
    kicad-cli ERC: 0 errors, 0 warnings. The b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
    [S06 STEP-Up Step-Down Reg.kicad_sch]
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2026-10-07 Add a PCAL9714 SPI I/O expander for the load-switch enables and faults
    New sheet S08 with U11 (PCAL9714, HVQFN-24) on the shared CLOCK/MOSI/MISO
    bus. J3.32, which was ENSBC, becomes its chip select nCSIO.
    - P0_0-P0_2 drive ENDAQ, ENSBC and ENEXT. J3.34/J3.36 become MCU_ENDAQ
    and MCU_ENEXT, and each reaches its enable only through a DNP 0R link
    (R96-R98). R95 links nCSIO to the expander CS.
    - P0_4-P0_6 read the U6/U7/U9 power-good signals, and P0_7 reads U5
    nFLT/nINT.
    - REGEN stays a direct J3.12 signal.
    - RESET is divided from +12V (R99 100K, R100 40.2K), so the expander
    stays in reset while the 12 V rail is off.
    - Pull-ups on CS and INT (R93, R94) and decoupling (C58, C59).
    The RE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
    [EVO2513-0_5_0.kicad_sch, S01 External Connectors.kicad_sch, S06 STEP-Up Step-Down Reg.kicad_sch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]
2026-10-07 Drive the expander RESET through a FET and use BSS138 for Q20-Q23
    The +12V divider on U11 RESET could back-power the expander and gave a
    weak logic high. Q23 now passes +3V3MCU to RESET while +12V is up, with
    its gate fed by R99 100K / R101 1M. R100 (now 100K) holds RESET low when
    +12V is off, and RESET can no longer rise above +3V3MCU.
    Q20-Q23 are now onsemi BSS138 in SOT-23, replacing the DFN1006
    DMN65D8LFB-7. The BSS138 has no gate zener, so gate leakage is at most
    100 nA on the 100K PG pull-ups and the Q23 gate divider. The README
    warns against ESD-protected substitutes.
    The root sheet change is KiCad reordering items only.
    [EVO2513-0_5_0.kicad_sch, S07 Load Switch and I-Sense.kicad_sch, S08 IO Expander.kicad_sch]
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2026-10-08 BOM consolidation, OVLO divider to 1%, U5 fixes and I2C config option
    - Consolidate passives: 1uF 50V to 0603, 100nF to 50V X7R 0402,
    10uF to 50V X7R 1210, 220nF to 0603, 10R to 0402 (100 -> 90 BOM lines)
    - TPS22811 OVLO divider 1M/102K 0.1% -> 1M/100K 1% (12.6V min trip)
    - U5 LM51772: C30 -> R102 10K to GND (VCC1 disabled), C32 -> 22uF 16V 0805,
    R29 1.9K -> 1.87K to sit inside the CFG4 window
    - Add DNP I2C configuration option for U5 (R103-R107) on J3.34/J3.36,
    shared with R97/R98 fallback
    - Document all changes in README.md
    [EVO2513-0_5_0.kicad_sch, S03 BMS Input and Output Monitor.kicad_sch, S04 Charger Regulation.kicad_sch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]
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2026-10-09 Update the PCB from the schematic for the BOM consolidation
    Brings in the footprint changes from 2fea505: C11-C14 and C24-C26 to
    1210, C8/C9/C55 and C16 to 0603, C32 to 0805, C37/C38 and R43/R44 to
    0402, C30 replaced by R102, and the U5 I2C option parts R103-R107.
    Q20 moved clear of C42's courtyard, with a few other parts and a via
    moved and zones refilled. Minimum hole clearance set to 0.182 mm.
    The schematic changes are KiCad reordering items, plus one item moved
    on S06.
    [EVO2513-0_5_0.kicad_pcb, EVO2513-0_5_0.kicad_sch, S03 BMS Input and Output Monitor.kicad_sch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]
2026-10-11 Final-revision value changes and standard R/C symbols
    Values (schematic and PCB):
    - C2 100uF -> 82uF, matching the ordered 35SVPF82M
    - C46, C47, C51 (TPS22811 DVDT) 4.7nF -> 1.8nF CC0402KRX7R9BB182 for a
    shorter output ramp
    - R24-R27 10R -> 0R; D9, D10 and R36 DNP
    - R14 0.01R -> 0.012R PA2512FKF7W0R012E
    Symbols:
    - All 160 resistors and capacitors now use Device:R, Device:C and
    Device:C_Polarized; the 76 per-value R/C symbols are removed from the
    project library. Connectivity is unchanged (netlist compared).
    - Value is now the displayed field instead of ALTIUM_VALUE, which had left
    R1, C39 and R54 showing their old values. ALTIUM_VALUE synced with Value
    on R1, C39, R54, D1, Q1, Q3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
2026-10-11 Retune load-switch OVLO and PG dividers; add design constraint notes
    - R90-R92 1M -> 1.07M: OVLO trips at 14.0 V (13.40-14.69 V) and recovers
    below 12.75 V (at least 12.23 V), so a tripped switch always comes back
    on the 12.03 V rail. R101 (Q23 gate divider) -> 1.07M to share the line.
    - PGTH dividers R59/R61/R76 1M -> 100K and R60/R62/R77 130K -> 13K: same
    10.43 V threshold, but the +-1 uA pin leakage now moves it 0.1 V, not
    1 V; worst-case rising 10.93 V instead of 11.84 V.
    - Schematic notes for the W16 constraints: J2 contacts (S01), R16 latching
    breaker and ED29/QE29 trip currents (S03), R19 vs L1 saturation (S04),
    R22 presence pull-up (S05), R42 and the U5 MODE/ILIMCOMP/VCC2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
2026-10-12 Add an 11 V undervoltage lockout to the DAQ load switch
    - R108 100K from +12V over R49 (100K -> 12K) on U6 EN/UVLO: on at 11.2 V
    (10.77-11.69 V), off at 10.17 V (9.83-10.66 V). The TPS22811's fixed
    hysteresis makes 11 V the turn-on point.
    - Q24 (BSS138) from EN/UVLO to GND takes over the enable. Its gate is biased
    from +12V by R109 100K / R110 27K (2.55 V), so U6 stays in shutdown when
    the expander is in reset, unpowered, or the MCU board is off.
    - The expander net ENDAQ is now nENDAQ, active low (S07, S08, root sheet).
    The gate stays under 3.3 V, so P0_0 can stay push-pull and the R97
    fallback can drive it from a 3.3 V MCU pin.
    - S07 note marks the DAQ circuit as deliberate; S08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
2026-10-12 Fit U5 BIAS to +12V by default; add firmware notes
    - R89 fitted, R88 DNP: U5 BIAS on +12V, the LM51772 datasheet's standard
    configuration (§7.3.5). On the 24 V supply the VCC2 regulator drops from
    12 V instead of 24 V; VSMART falls back to VIN at start-up or if +12V
    collapses. nRST stays on DCBMS. The field units have BIAS on DCBMS.
    - FIRMWARE_NOTES.md: SPI and expander set-up (inverted DAQ enable on P0_0,
    25% drive, polling, reset behaviour), load-switch thresholds, current
    monitor scaling, U5 I2C build defaults, LTC1960 breaker and R14 changes,
    and pack comms pass-through. Linked from the README.
2026-10-12 Update the PCB from the schematic; 0.25 mm signal tracks
    - Update PCB from Schematic (run in KiCad): adds Q24 and R108-R110, swaps
    Q4/Q5/Q12-Q15 to Package_SON:Diodes_PowerDI3333-8 and R41/R45 to 1210,
    and applies the value, DNP and net changes. Parity is clean; the new
    parts are not yet placed or routed.
    - 97 signal-track segments on 30 nets 0.3 -> 0.25 mm, and the Default net
    class track width 0.2 -> 0.25 mm. Power classes, GND, +5V, U5 gate drive
    and bootstrap, VCC2 and the charger gate drive stay at 0.3 mm.
2026-10-12 Place the U5 option links; drop R103; PCB DRC clean-up
    - Place the U5 MODE/BIAS links (R86-R89) and the CFG/I2C links near U5,
    clear of the +12V F.Cu pour.
    - Move the I2C option links R104-R107 to a row beside J3 (between R12 and
    C56), next to J3.30 +3V3MCU, J3.34 and J3.36. GND F.Cu near J3 loses
    about 2 % with no new islands.
    - Remove R103: the I2C build now changes R38 (CFG1) to 0R instead. Note
    added at R38 on S06; S06 I2C note, README and FIRMWARE_NOTES updated.
    - Route the BIAS/MODE/VCC2 links and fix the DRC clearance, short and
    courtyard errors (manual edits in KiCad).
    DRC with schematic parity: 285 violations, none clearance, short or
    courtyard (library, padstack, silk an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
2026-10-12 PCB routing and DRC clean-up; teardrops; title block to 0.6.0
    PCB (manual edits in KiCad):
    - Route more of the new parts: +59 track segments, +7 vias, and a small
    +3V3MCU pour on In6.Cu near J3 (x 159, y 130-134).
    - Add teardrops (319). Teardrop and zone defaults updated in the
    project settings.
    - DRC with schematic parity: 285 -> 98 violations (64 padstack,
    27 unrouted pads, 19 + 2 silk, 8 text thickness, 5 dangling vias).
    No parity, clearance, short or courtyard errors.
    Project: title-block variables BOARD_NUMBER EVO2513-0.6.0 and
    COMP_NAME evoSonic; extra track width (0.15/0.5 mm) presets.
    Schematics: cosmetic only (field positions, element order, S03 FET
    pin entries). No value,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
2026-10-13 Complete PCB routing; remove stray PGDAQ stub
    DRC: 0 errors, 0 unconnected items.
2026-10-13 New PG-TDSON-8-33 footprint for Q16/Q17/Q19; set SMD/THT types; BON pads to TP
    - Q16/Q17/Q19 move to Infineon_PG-TDSON-8-33_5.48x5.15mm_P1.27mm, built from
    the IAUCN04S7L019 datasheet land pattern: centred copper, separate stencil
    apertures (2x2 windows, ~58% on the exposed pad). Pad numbering matches the
    existing symbol (source bar = 1, exposed pad = 8).
    - Set the footprint type on 42 untyped imported parts (37 SMD, J1/J2/J4/J5/J6
    through-hole), on the board and in the project library, so they reach the
    SMD position file.
    - Rename pogo test pads BON1-26 to TP1-26, exclude them from BOM and position
    files, and point the 0.3 mm pad-to-pad DRC rule at TP*.
    DRC: 0 errors, 0 unconne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
2026-10-13 Spacers to SMD on one footprint; drop Altium no-paste pad margins
    - M1-M6 (Wurth 78614150960, tape-fed, reflowed) are set to SMD so they reach
    the SMD position file. M1 moves to the same footprint as M2-M6; the
    duplicate lowercase spacer footprint is removed.
    - Remove the Altium "no paste" solder_paste_margin (and the paste layer it
    blanked) from the spacer, U1/U5 exposed-pad and TP test-pad pads, on the
    board and in the library. Clears all 34 padstack DRC warnings; copper,
    mask and paste Gerbers are unchanged apart from draw order.
    DRC: 0 errors, 0 unconnected.
2026-10-13 Fiducials: placement file, no paste, 3 mm mask opening with copper keepout
    - Fiducial1/2 are SMD and in the position file, excluded from the BOM
    (schematic, symbol library and footprints agree).
    - Remove the paste layer from the fiducial pad; the stencil was printing a
    1.27 mm paste dot on each fiducial.
    - Fiducial-50 gets a 0.865 mm mask margin (3.0 mm opening on the 1.27 mm pad)
    and a 3.2 mm F.Cu keepout (no pour, tracks or vias) so no other copper shows
    in the opening.
    - Remove two GND stitching vias inside Fiducial1's clear area; zones refilled.
    DRC: 0 errors, 0 unconnected. ERC: 0 violations.
2026-10-13 U11 PCAL9714HNMP 3D model; FET zone reshaping; R23/R82-R85 DNP
    - U11 moves to a project-library copy of HVQFN-24-1EP_4x4mm_P0.5mm_EP2.6x2.6mm
    linked to ${KIPRJMOD}/PCAL9714HNMP.stp (STEP later embedded; file not kept). Schematic and Lattech
    symbol point at the project copy.
    - Board updated from the schematic (symbol pin data on the swapped
    footprints) and zone fills reshaped around the FETs.
    - R23, R82-R85 (NEQ) set DNP in the schematic and on the board.
    DRC: 0 errors, 0 unconnected, 0 schematic parity issues. ERC: 0 violations.
2026-10-13 README: note the intentional J3.24/J3.28 thermistor swap
    BMSTEMP and REGTEMP were swapped between J3 pins 24 and 28 in 6ce5d68,
    whose message says there were no net changes. Record the new mapping for
    the firmware.
2026-10-13 U5 I2C configuration by default; 10K I2C pull-ups; fix expander port map
    - Fit the U5 (LM51772) I2C build: R104-R107 fitted, R38 6.49K -> 0R
    (I2C at 0x6A), R29/R30 DNP. R97/R98 stay unfitted (same J3 pins).
    - R106/R107 pull-ups 2.2K -> 10K for slow edges (EMC); limits the bus
    to 100 kHz standard mode.
    - Docs and the S08 note: P0_0 drives ENSBC and P0_1 drives nENDAQ
    (active low), matching the routed schematic and board.
    - J3.34/J3.36 keep the MCU_ENDAQ/MCU_ENEXT net names.
    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
2026-10-13 Embed 3D models for U2, U8/U10 and U11; board touch-ups
    - LTC4365 (U2, DFN 2x3), TLV9002 (U8/U10, WSON 2x2) and PCAL9714 (U11,
    HVQFN-24) models are embedded in their project-library footprints and
    the board copies, like the rest of the project library. No footprint
    links a model by project path any more.
    - Board: silkscreen reference positions on C5, C6, D2 and R11; zone
    clean-up; Q5/Q15 pin names from the schematic.
    DRC: 0 errors, 0 unconnected, 0 schematic parity issues.
2026-10-13 Remove unused footprints and 3D models
    - Project library: drop the old Altium PG-TDSON-8-33 B6.44 footprint
    (replaced by Infineon_PG-TDSON-8-33_5.48x5.15mm_P1.27mm) and
    FET 3-Pin DFN1006 (Q20-Q22 are SOT-23). Neither is used by the board,
    the schematic or a symbol default.
    - Remove 744393580068.stp, unused since the import, and its README entry.
    - Board: drop 10 unreferenced board-level embedded STEP files (Altium
    import ceramic/resistor models, DFN1006, RES_FZ-R005E-3). Every
    footprint carries its own copy of its model.
    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
2026-10-13 Charger rework, 0.5/0.2 mm vias, and current-check vias
    - Move and reroute D2, D3, C16, C8 and TH1 in the charger area.
    - Change all vias to 0.5 mm pad / 0.2 mm drill.
    - Add 33 through vias in the group "Current-check vias". Each one
    continues the rows and columns of the via array next to it. They
    reduce the highest via current at Q17/Q19 GND, SW1, SW2, L2,
    DCSENSED, DCPATH, GDINPUT and +12V (R48/R85).
    - Autoplace the reference/value fields on two S06 symbols.
    Open DRC error: a GND via at (189.20, 135.60) is 0.074 mm from
    the /DCCHARGER track on In6.
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
